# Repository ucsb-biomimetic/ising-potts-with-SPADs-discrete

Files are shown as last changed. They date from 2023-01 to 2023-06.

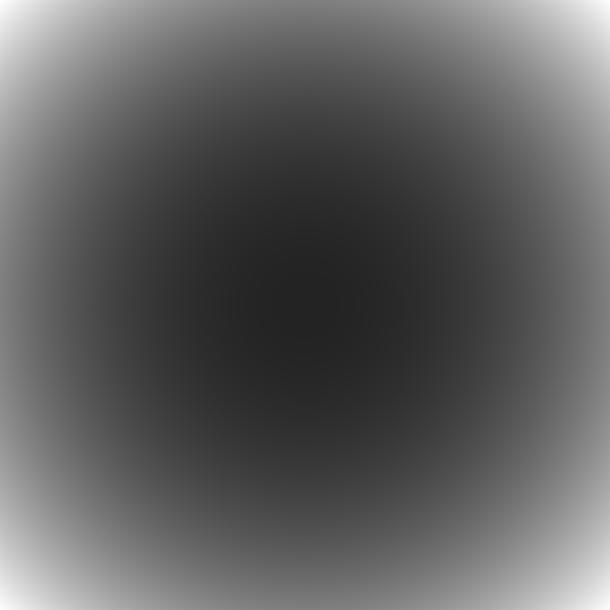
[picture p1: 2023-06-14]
VRSPAD-144/pcb_design/illumination box/illumination_mask.png

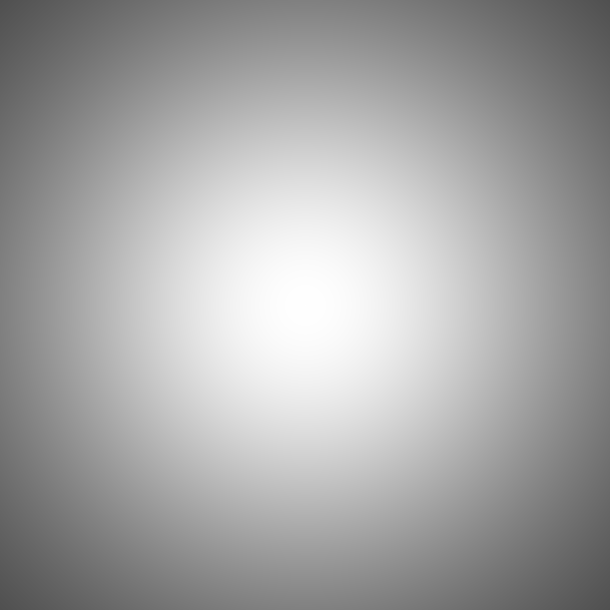
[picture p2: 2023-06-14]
VRSPAD-144/pcb_design/illumination box/intensity_map.png

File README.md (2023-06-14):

# ising-potts-with-SPADs-discrete
CMOS compatible Ising and Potts Annealing Using Single-photon Avalanche Diodes: Design files

The proof-of-concept for SPAD Ising and Potts CTMC (continuous-time markov chain) relies on the key files provided here.  There are two sets of files for 16-circuit and 144-circuit implementations of variable rate SPADs; the 144-circuit version was created second, to enable demonstrations of combinatorial problem solving.

For each implementation, there are three groups of files: one for PCB design, one for FPGA logic, and one for data and code. The code runs tests on the physical system specified by the PCB and FPGA design, and saves data results.

For the 16-circuit version, both the code and the FPGA configuration for the system lies entirely on the Zedboard; a Vivado 2020.1 project is provided, which was used to create the Zedboard FPGA configuration. The processor side of the Zedboard was configured to run linux and the PYNQ environment, so data collection and control of the proof-of-concept aparatus was done through a jupyter-notebook running locally on the zedboard (and accessed from a PC over ethernet).

Since the provided jupyter notebook runs in concert with the Zedboard FPGA and the hardware we connect to the FPGA, it cannot be run in its entirety without fully replicating the hardware as well.  However, many intermediate data are saved alongside the notebook, so one may see the interaction between code and results.  

For the 144-circuit version, the FPGA logic was redesigned to expose a SPI interface that could be accessed over a USB connection. Thus the Python code ran directly on a PC.  In addition, the FPGA board (A Digilent Genesys 2) was configured using Vivado 2020.1 in non-project mode, so rather than a Vivado project, regular verilog files and a Vivado TCL script provided.

While many of the scripts still require a connection to the hardware to run correctly, some scripts that only perform data plotting can be run without the hardware.

All experimental data in the paper is drawn from one of the two experimental systems specified here.

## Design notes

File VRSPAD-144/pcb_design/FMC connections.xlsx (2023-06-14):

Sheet: Sheet1
A | 0 | 1 | A1 | GND | #N/A | D8 | 141 | LA01_P_CC | H5 | 127 | CLK0_M2C_N
A | 1 | 2 | A2 | DP1_M2C_P | #N/A | D9 | 142 | LA01_N_CC | H4 | 128 | CLK0_M2C_P
A | 2 | 3 | A3 | DP1_M2C_N | #N/A | E10 | 144 | HA09_N | G3 | 131 | CLK1_M2C_N
A | 3 | 4 | A4 | GND | #N/A | E12 | 111 | HA13_P | G2 | 132 | CLK1_M2C_P
A | 4 | 5 | A5 | GND | #N/A | E13 | 105 | HA13_N | K5 | 122 | CLK2_BIDIR_N
A | 5 | 6 | A6 | DP2_M2C_P | #N/A | E15 | 99 | HA16_P | K4 | 124 | CLK2_BIDIR_P
A | 6 | 7 | A7 | DP2_M2C_N | #N/A | E16 | 93 | HA16_N | F5 | 135 | HA00_N_CC
A | 7 | 8 | A8 | GND | #N/A | E18 | 87 | HA20_P | F4 | 136 | HA00_P_CC
A | 8 | 9 | A9 | GND | #N/A | E19 | 81 | HA20_N | E3 | 138 | HA01_N_CC
A | 9 | 10 | A10 | DP3_M2C_P | #N/A | E2 | 137 | HA01_P_CC | E2 | 137 | HA01_P_CC
A | 10 | 11 | A11 | DP3_M2C_N | #N/A | E21 | 75 | HB03_P | K8 | 117 | HA02_N
A | 11 | 12 | A12 | GND | #N/A | E22 | 69 | HB03_N | K7 | 120 | HA02_P
A | 12 | 13 | A13 | GND | #N/A | E24 | 63 | HB05_P | J7 | 121 | HA03_N
A | 13 | 14 | A14 | DP4_M2C_P | #N/A | E25 | 57 | HB05_N | J6 | 123 | HA03_P
A | 14 | 15 | A15 | DP4_M2C_N | #N/A | E27 | 51 | HB09_P | F8 | 133 | HA04_N
A | 15 | 16 | A16 | GND | #N/A | E28 | 45 | HB09_N | F7 | 134 | HA04_P
A | 16 | 17 | A17 | GND | #N/A | E3 | 138 | HA01_N_CC | E7 | 140 | HA05_N
A | 17 | 18 | A18 | DP5_M2C_P | #N/A | E30 | 39 | HB13_P | E6 | 139 | HA05_P
A | 18 | 19 | A19 | DP5_M2C_N | #N/A | E31 | 33 | HB13_N | K11 | 106 | HA06_N
A | 19 | 20 | A20 | GND | #N/A | E33 | 24 | HB19_P | K10 | 112 | HA06_P
A | 20 | 21 | A21 | GND | #N/A | E34 | 21 | HB19_N | J10 | 113 | HA07_N
A | 21 | 22 | A22 | DP1_C2M_P | #N/A | E36 | 12 | HB21_P | J9 | 118 | HA07_P
A | 22 | 23 | A23 | DP1_C2M_N | #N/A | E37 | 1 | HB21_N | F11 | 110 | HA08_N
A | 23 | 24 | A24 | GND | #N/A | E6 | 139 | HA05_P | F10 | 116 | HA08_P
A | 24 | 25 | A25 | GND | #N/A | E7 | 140 | HA05_N | E10 | 144 | HA09_N
A | 25 | 26 | A26 | DP2_C2M_P | #N/A | E9 | 143 | HA09_P | E9 | 143 | HA09_P
A | 26 | 27 | A27 | DP2_C2M_N | #N/A | F10 | 116 | HA08_P | K14 | 94 | HA10_N
A | 27 | 28 | A28 | GND | #N/A | F11 | 110 | HA08_N | K13 | 100 | HA10_P
A | 28 | 29 | A29 | GND | #N/A | F13 | 104 | HA12_P | J13 | 101 | HA11_N
A | 29 | 30 | A30 | DP3_C2M_P | #N/A | F14 | 98 | HA12_N | J12 | 107 | HA11_P
A | 30 | 31 | A31 | DP3_C2M_N | #N/A | F16 | 92 | HA15_P | F14 | 98 | HA12_N
A | 31 | 32 | A32 | GND | #N/A | F17 | 86 | HA15_N | F13 | 104 | HA12_P
A | 32 | 33 | A33 | GND | #N/A | F19 | 80 | HA19_P | E13 | 105 | HA13_N
A | 33 | 34 | A34 | DP4_C2M_P | #N/A | F20 | 74 | HA19_N | E12 | 111 | HA13_P
A | 34 | 35 | A35 | DP4_C2M_N | #N/A | F22 | 68 | HB02_P | J16 | 89 | HA14_N
A | 35 | 36 | A36 | GND | #N/A | F23 | 62 | HB02_N | J15 | 95 | HA14_P
A | 36 | 37 | A37 | GND | #N/A | F25 | 56 | HB04_P | F17 | 86 | HA15_N
A | 37 | 38 | A38 | DP5_C2M_P | #N/A | F26 | 50 | HB04_N | F16 | 92 | HA15_P
A | 38 | 39 | A39 | DP5_C2M_N | #N/A | F28 | 44 | HB08_P | E16 | 93 | HA16_N
A | 39 | 40 | A40 | GND | #N/A | F29 | 38 | HB08_N | E15 | 99 | HA16_P
B | 40 | 1 | B1 | CLK_DIR | #N/A | F31 | 32 | HB12_P | K17 | 82 | HA17_N_CC
B | 41 | 2 | B2 | GND | #N/A | F32 | 27 | HB12_N | K16 | 88 | HA17_P_CC
B | 42 | 3 | B3 | GND | #N/A | F34 | 20 | HB16_P | J19 | 77 | HA18_N
B | 43 | 4 | B4 | DP9_M2C_P | #N/A | F35 | 15 | HB16_N | J18 | 83 | HA18_P
B | 44 | 5 | B5 | DP9_M2C_N | #N/A | F37 | 2 | HB20_P | F20 | 74 | HA19_N
B | 45 | 6 | B6 | GND | #N/A | F38 | 3 | HB20_N | F19 | 80 | HA19_P
B | 46 | 7 | B7 | GND | #N/A | F4 | 136 | HA00_P_CC | E19 | 81 | HA20_N
B | 47 | 8 | B8 | DP8_M2C_P | #N/A | F5 | 135 | HA00_N_CC | E18 | 87 | HA20_P
B | 48 | 9 | B9 | DP8_M2C_N | #N/A | F7 | 134 | HA04_P | K20 | 70 | HA21_N
B | 49 | 10 | B10 | GND | #N/A | F8 | 133 | HA04_N | K19 | 76 | HA21_P
B | 50 | 11 | B11 | GND | #N/A | G10 | 115 | LA03_N | J22 | 65 | HA22_N
B | 51 | 12 | B12 | DP7_M2C_P | #N/A | G12 | 109 | LA08_P | J21 | 71 | HA22_P
B | 52 | 13 | B13 | DP7_M2C_N | #N/A | G13 | 103 | LA08_N | K23 | 58 | HA23_N
B | 53 | 14 | B14 | GND | #N/A | G15 | 97 | LA12_P | K22 | 64 | HA23_P
B | 54 | 15 | B15 | GND | #N/A | G16 | 91 | LA12_N | K26 | 46 | HB00_N_CC
B | 55 | 16 | B16 | DP6_M2C_P | #N/A | G18 | 85 | LA16_P | K25 | 52 | HB00_P_CC
B | 56 | 17 | B17 | DP6_M2C_N | #N/A | G19 | 79 | LA16_N | J25 | 53 | HB01_N
B | 57 | 18 | B18 | GND | #N/A | G2 | 132 | CLK1_M2C_P | J24 | 59 | HB01_P
B | 58 | 19 | B19 | GND | #N/A | G21 | 73 | LA20_P | F23 | 62 | HB02_N
B | 59 | 20 | B20 | GBTCLK1_M2C_P | #N/A | G22 | 67 | LA20_N | F22 | 68 | HB02_P
B | 60 | 21 | B21 | GBTCLK1_M2C_N | #N/A | G24 | 61 | LA22_P | E22 | 69 | HB03_N
B | 61 | 22 | B22 | GND | #N/A | G25 | 55 | LA22_N | E21 | 75 | HB03_P
B | 62 | 23 | B23 | GND | #N/A | G27 | 49 | LA25_P | F26 | 50 | HB04_N
B | 63 | 24 | B24 | DP9_C2M_P | #N/A | G28 | 43 | LA25_N | F25 | 56 | HB04_P
B | 64 | 25 | B25 | DP9_C2M_N | #N/A | G3 | 131 | CLK1_M2C_N | E25 | 57 | HB05_N
B | 65 | 26 | B26 | GND | #N/A | G30 | 37 | LA29_P | E24 | 63 | HB05_P
B | 66 | 27 | B27 | GND | #N/A | G31 | 31 | LA29_N | K29 | 34 | HB06_N_CC
B | 67 | 28 | B28 | DP8_C2M_P | #N/A | G33 | 23 | LA31_P | K28 | 40 | HB06_P_CC
B | 68 | 29 | B29 | DP8_C2M_N | #N/A | G34 | 19 | LA31_N | J28 | 41 | HB07_N
B | 69 | 30 | B30 | GND | #N/A | G36 | 11 | LA33_P | J27 | 47 | HB07_P
B | 70 | 31 | B31 | GND | #N/A | G37 | 4 | LA33_N | F29 | 38 | HB08_N
B | 71 | 32 | B32 | DP7_C2M_P | #N/A | G6 | 130 | LA00_P_CC | F28 | 44 | HB08_P
B | 72 | 33 | B33 | DP7_C2M_N | #N/A | G7 | 129 | LA00_N_CC | E28 | 45 | HB09_N
B | 73 | 34 | B34 | GND | #N/A | G9 | 119 | LA03_P | E27 | 51 | HB09_P
B | 74 | 35 | B35 | GND | #N/A | H10 | 114 | LA04_P | K32 | 25 | HB10_N
B | 75 | 36 | B36 | DP6_C2M_P | #N/A | H11 | 108 | LA04_N | K31 | 28 | HB10_P
B | 76 | 37 | B37 | DP6_C2M_N | #N/A | H13 | 102 | LA07_P | J31 | 29 | HB11_N
B | 77 | 38 | B38 | GND | #N/A | H14 | 96 | LA07_N | J30 | 35 | HB11_P
B | 78 | 39 | B39 | GND | #N/A | H16 | 90 | LA11_P | F32 | 27 | HB12_N
B | 79 | 40 | B40 | RES0 | #N/A | H17 | 84 | LA11_N | F31 | 32 | HB12_P
C | 80 | 1 | C1 | GND | #N/A | H19 | 78 | LA15_P | E31 | 33 | HB13_N
C | 81 | 2 | C2 | DP0_C2M_P | #N/A | H20 | 72 | LA15_N | E30 | 39 | HB13_P
C | 82 | 3 | C3 | DP0_C2M_N | #N/A | H22 | 66 | LA19_P | K35 | 13 | HB14_N
C | 83 | 4 | C4 | GND | #N/A | H23 | 60 | LA19_N | K34 | 16 | HB14_P
C | 84 | 5 | C5 | GND | #N/A | H25 | 54 | LA21_P | J34 | 17 | HB15_N
C | 85 | 6 | C6 | DP0_M2C_P | #N/A | H26 | 48 | LA21_N | J33 | 22 | HB15_P
C | 86 | 7 | C7 | DP0_M2C_N | #N/A | H28 | 42 | LA24_P | F35 | 15 | HB16_N
C | 87 | 8 | C8 | GND | #N/A | H29 | 36 | LA24_N | F34 | 20 | HB16_P
C | 88 | 9 | C9 | GND | #N/A | H31 | 30 | LA28_P | K38 | 8 | HB17_N_CC
C | 89 | 10 | C10 | LA06_P | #N/A | H32 | 26 | LA28_N | K37 | 9 | HB17_P_CC
C | 90 | 11 | C11 | LA06_N | #N/A | H34 | 18 | LA30_P | J37 | 7 | HB18_N
C | 91 | 12 | C12 | GND | #N/A | H35 | 14 | LA30_N | J36 | 10 | HB18_P
C | 92 | 13 | C13 | GND | #N/A | H37 | 6 | LA32_P | E34 | 21 | HB19_N
C | 93 | 14 | C14 | LA10_P | #N/A | H38 | 5 | LA32_N | E33 | 24 | HB19_P
C | 94 | 15 | C15 | LA10_N | #N/A | H4 | 128 | CLK0_M2C_P | F38 | 3 | HB20_N
C | 95 | 16 | C16 | GND | #N/A | H5 | 127 | CLK0_M2C_N | F37 | 2 | HB20_P
C | 96 | 17 | C17 | GND | #N/A | H7 | 126 | LA02_P | E37 | 1 | HB21_N
C | 97 | 18 | C18 | LA14_P | #N/A | H8 | 125 | LA02_N | E36 | 12 | HB21_P
C | 98 | 19 | C19 | LA14_N | #N/A | J10 | 113 | HA07_N | G7 | 129 | LA00_N_CC
C | 99 | 20 | C20 | GND | #N/A | J12 | 107 | HA11_P | G6 | 130 | LA00_P_CC
C | 100 | 21 | C21 | GND | #N/A | J13 | 101 | HA11_N | D9 | 142 | LA01_N_CC
C | 101 | 22 | C22 | LA18_P_CC | #N/A | J15 | 95 | HA14_P | D8 | 141 | LA01_P_CC
C | 102 | 23 | C23 | LA18_N_CC | #N/A | J16 | 89 | HA14_N | H8 | 125 | LA02_N
C | 103 | 24 | C24 | GND | #N/A | J18 | 83 | HA18_P | H7 | 126 | LA02_P
C | 104 | 25 | C25 | GND | #N/A | J19 | 77 | HA18_N | G10 | 115 | LA03_N
C | 105 | 26 | C26 | LA27_P | #N/A | J21 | 71 | HA22_P | G9 | 119 | LA03_P
C | 106 | 27 | C27 | LA27_N | #N/A | J22 | 65 | HA22_N | H11 | 108 | LA04_N
C | 107 | 28 | C28 | GND | #N/A | J24 | 59 | HB01_P | H10 | 114 | LA04_P
C | 108 | 29 | C29 | GND | #N/A | J25 | 53 | HB01_N | H14 | 96 | LA07_N
C | 109 | 30 | C30 | SCL | #N/A | J27 | 47 | HB07_P | H13 | 102 | LA07_P
C | 110 | 31 | C31 | SDA | #N/A | J28 | 41 | HB07_N | G13 | 103 | LA08_N
C | 111 | 32 | C32 | GND | #N/A | J30 | 35 | HB11_P | G12 | 109 | LA08_P
C | 112 | 33 | C33 | GND | #N/A | J31 | 29 | HB11_N | H17 | 84 | LA11_N
C | 113 | 34 | C34 | GA0 | #N/A | J33 | 22 | HB15_P | H16 | 90 | LA11_P
C | 114 | 35 | C35 | 12P0V | #N/A | J34 | 17 | HB15_N | G16 | 91 | LA12_N
C | 115 | 36 | C36 | GND | #N/A | J36 | 10 | HB18_P | G15 | 97 | LA12_P
C | 116 | 37 | C37 | 12P0V | #N/A | J37 | 7 | HB18_N | H20 | 72 | LA15_N
C | 117 | 38 | C38 | GND | #N/A | J6 | 123 | HA03_P | H19 | 78 | LA15_P
C | 118 | 39 | C39 | 3P3V | #N/A | J7 | 121 | HA03_N | G19 | 79 | LA16_N
C | 119 | 40 | C40 | GND | #N/A | J9 | 118 | HA07_P | G18 | 85 | LA16_P
D | 120 | 1 | D1 | PG_C2M | #N/A | K10 | 112 | HA06_P | H23 | 60 | LA19_N
D | 121 | 2 | D2 | GND | #N/A | K11 | 106 | HA06_N | H22 | 66 | LA19_P
D | 122 | 3 | D3 | GND | #N/A | K13 | 100 | HA10_P | G22 | 67 | LA20_N
D | 123 | 4 | D4 | GBTCLK0_M2C_P | #N/A | K14 | 94 | HA10_N | G21 | 73 | LA20_P
D | 124 | 5 | D5 | GBTCLK0_M2C_N | #N/A | K16 | 88 | HA17_P_CC | H26 | 48 | LA21_N
D | 125 | 6 | D6 | GND | #N/A | K17 | 82 | HA17_N_CC | H25 | 54 | LA21_P
D | 126 | 7 | D7 | GND | #N/A | K19 | 76 | HA21_P | G25 | 55 | LA22_N
D | 127 | 8 | D8 | LA01_P_CC | 141 | K20 | 70 | HA21_N | G24 | 61 | LA22_P
D | 128 | 9 | D9 | LA01_N_CC | 142 | K22 | 64 | HA23_P | H29 | 36 | LA24_N
D | 129 | 10 | D10 | GND | #N/A | K23 | 58 | HA23_N | H28 | 42 | LA24_P
D | 130 | 11 | D11 | LA05_P | #N/A | K25 | 52 | HB00_P_CC | G28 | 43 | LA25_N
D | 131 | 12 | D12 | LA05_N | #N/A | K26 | 46 | HB00_N_CC | G27 | 49 | LA25_P
D | 132 | 13 | D13 | GND | #N/A | K28 | 40 | HB06_P_CC | H32 | 26 | LA28_N
D | 133 | 14 | D14 | LA09_P | #N/A | K29 | 34 | HB06_N_CC | H31 | 30 | LA28_P
D | 134 | 15 | D15 | LA09_N | #N/A | K31 | 28 | HB10_P | G31 | 31 | LA29_N
D | 135 | 16 | D16 | GND | #N/A | K32 | 25 | HB10_N | G30 | 37 | LA29_P
D | 136 | 17 | D17 | LA13_P | #N/A | K34 | 16 | HB14_P | H35 | 14 | LA30_N
D | 137 | 18 | D18 | LA13_N | #N/A | K35 | 13 | HB14_N | H34 | 18 | LA30_P
D | 138 | 19 | D19 | GND | #N/A | K37 | 9 | HB17_P_CC | G34 | 19 | LA31_N
D | 139 | 20 | D20 | LA17_P_CC | #N/A | K38 | 8 | HB17_N_CC | G33 | 23 | LA31_P
D | 140 | 21 | D21 | LA17_N_CC | #N/A | K4 | 124 | CLK2_BIDIR_P | H38 | 5 | LA32_N
D | 141 | 22 | D22 | GND | #N/A | K5 | 122 | CLK2_BIDIR_N | H37 | 6 | LA32_P
D | 142 | 23 | D23 | LA23_P | #N/A | K7 | 120 | HA02_P | G37 | 4 | LA33_N
D | 143 | 24 | D24 | LA23_N | #N/A | K8 | 117 | HA02_N | G36 | 11 | LA33_P
D | 144 | 25 | D25 | GND | #N/A | D14 | sck | LA09_P
D | 145 | 26 | D26 | LA26_P | #N/A | D12 | mosi | LA05_N
D | 146 | 27 | D27 | LA26_N | #N/A | D11 | miso | LA05_P
D | 147 | 28 | D28 | GND | #N/A | C10 | cs2 | LA06_P
D | 148 | 29 | D29 | TCK | #N/A | C11 | cs3 | LA06_N
D | 149 | 30 | D30 | TDI | #N/A | C14 | cs4 | LA10_P
D | 150 | 31 | D31 | TDO | #N/A | C15 | cs5 | LA10_N
D | 151 | 32 | D32 | 3P3VAUX | #N/A | C19 | A0 | LA14_N
D | 152 | 33 | D33 | TMS | #N/A | D20 | A1 | LA17_P_CC
D | 153 | 34 | D34 | TRST_L | #N/A | D27 | WR1 | LA26_N
D | 154 | 35 | D35 | GA1 | #N/A | C27 | WR2 | LA27_N
D | 155 | 36 | D36 | 3P3V | #N/A | D26 | WR3 | LA26_P
D | 156 | 37 | D37 | GND | #N/A | C26 | WR4 | LA27_P
D | 157 | 38 | D38 | 3P3V | #N/A | D24 | WR5 | LA23_N
D | 158 | 39 | D39 | GND | #N/A | C23 | WR6 | LA18_N_CC
D | 159 | 40 | D40 | 3P3V | #N/A | D23 | WR7 | LA23_P
E | 160 | 1 | E1 | GND | #N/A | C22 | WR8 | LA18_P_CC
E | 161 | 2 | E2 | HA01_P_CC | 137 | D21 | WR9 | LA17_N_CC
E | 162 | 3 | E3 | HA01_N_CC | 138 | C18 | HBEN | LA14_P
E | 163 | 4 | E4 | GND | #N/A
E | 164 | 5 | E5 | GND | #N/A
E | 165 | 6 | E6 | HA05_P | 139
E | 166 | 7 | E7 | HA05_N | 140
E | 167 | 8 | E8 | GND | #N/A
E | 168 | 9 | E9 | HA09_P | 143
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

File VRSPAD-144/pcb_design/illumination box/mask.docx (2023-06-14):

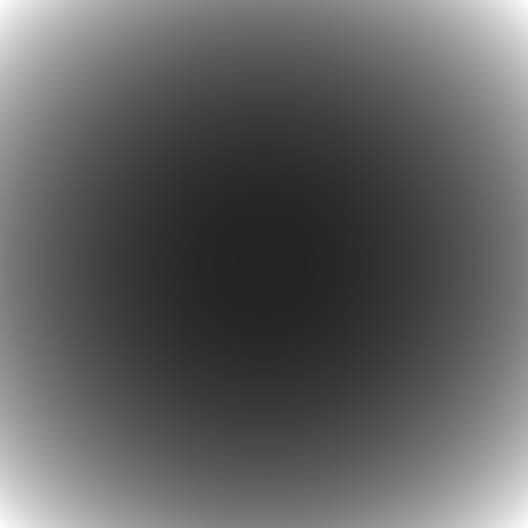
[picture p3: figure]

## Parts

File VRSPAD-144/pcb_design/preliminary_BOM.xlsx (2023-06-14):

item | PN | value | package | buy # | price each | line total | digikey link
modules
genesys 2 fpga |  |  |  | 1 |  | 0 | mouser
HX-8K eval board |  |  |  | 1 |  | 0 | mouser
144 element SiPM array | ARRAYC-30035-144P-PCB |  |  | 1 | 2255 | 2255 | mouser
adafruit FTDI breakout |  |  |  | 2 |  | 0 | mouser
connectors
bannana jack, black | CT3151SP-0 |  |  | 3 | 2.4 | 7.2 | mouser
bannana jack, red | CT3151SP-2 |  |  | 3 | 2.4 | 7.2 | mouser
bannana jack, green | CT3151SP-5 |  |  | 3 | 2.4 | 7.2 | mouser
FMC | ASP-134488-01 |  |  | 1 | 29.88 | 29.88 | mouser
SiPM array connector | QSE-040-01-F-D-A |  |  | 4 | 12.69 | 50.76 | mouser
PMOD cables |  |  |  | 7 |  |  | mouser
3A regulator | LD1085D2M-R |  | D2PAK/TO-263-3 | 3 | 2.08 | 6.24 | mouser
high voltage op amp | OPA990IDBVR |  | SOT-23-5 | 10 | 1.19 | 11.9 | https://www.digikey.com/en/products/detail/texas-instruments/OPA990IDBVR/11502246
medium power op amp | AD8531ARTZ |  | SOT-23-5 | 10 | 1.01 | 10.1 | https://www.digikey.com/en/products/detail/analog-devices-inc/AD8531ARTZ-REEL7/671108
global parameter DAC | AD5676ARUZ |  | TSSOP-20 | 2 | 21.46 | 42.92 | https://www.digikey.com/en/products/detail/analog-devices-inc/AD5676ARUZ-REEL7/5175797
signal circuits (array)
220 MHz 125 mA, 210 V/us | ADA4891-4ARUZ-R7 |  | TSSOP-14 | 2 | 4.04 | 8.08 | https://www.digikey.com/en/products/detail/analog-devices-inc/ADA4891-4ARUZ-R7/2606522
720 MHz quad op amp | LTC6254HMS |  | MSOP-14 | 2 | 12.87 | 25.74 | https://www.digikey.com/en/products/detail/analog-devices-inc/LTC6254HMS-PBF/2399171
quad DAC | AD7305BRUZ |  | TSSOP-20 | 2 | 13.4 | 26.8 | https://www.digikey.com/en/products/detail/analog-devices-inc/AD7305BRUZ-REEL7/760440
quad DAC | MAX5100AEUP+ |  |  |  |  |  | out of stock
quad comparator | MAX9201EUE+T |  | TSSOP-16 | 2 | 7 | 14 | https://www.digikey.com/en/products/detail/analog-devices-inc-maxim-integrated/MAX9201EUE-T/1499399
quad comparator | AD8564ARUZ |  | TSSOP-16 | 2 | 11.6 | 23.2 | https://www.digikey.com/en/products/detail/analog-devices-inc/AD8564ARUZ-REEL/751174
tia feedback resistor | resistor book - low R | 5.1k | _0402
end cap parts
octal level shifter | FXMA108BQX |  | DQFN-20 | 10 | 2.03 | 20.3 | https://www.digikey.com/en/products/detail/onsemi/FXMA108BQX/2287318?s=N4IgTCBcDaIGIA0CyBBAjABgBwgLoF8g
quad capacitor |  | 220n | _0508
quad resistor |  | _470 | _0508
0402 cap book
0.1u 0402 caps
3v3 version
quad comparator | MAX964EEE |  | QSOP-16 | 7 | 11 | 77 | https://www.digikey.com/en/products/detail/analog-devices-inc-maxim-integrated/MAX964EEE/948247
quad comparator | MAX964EEE |  | QSOP-16 | 35 | 8.63 | 302.05 | https://www.digikey.com/en/products/detail/analog-devices-inc-maxim-integrated/MAX964EEE/371671
quad amplifier | ADA4891-4ARUZ-R7 |  | TSSOP-14 | 43 | 4.04 | 173.72 | https://www.digikey.com/en/products/detail/analog-devices-inc/ADA4891-4ARUZ-R7/2606522
quad DAC | AD5335 |  | TSSOP-24 | 43 | 6.98 | 300.14 | https://www.digikey.com/en/products/detail/analog-devices-inc/AD5335BRU/11540879
720 MHz quad op amp | LTC6254HMS |  | MSOP-16 | 3 | 10.43 | 31.29

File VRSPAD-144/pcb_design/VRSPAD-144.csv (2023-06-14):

Source: | C:\Users\William\Documents\School files\research\ising potts SPAD CTMC node proof of concept\VRSPAD-144-pcb\VRSPAD-144.kicad_sch
Date: | 4/5/2023 1:55:15 PM
Tool: | Eeschema 7.0.1
Generator: | C:\Program Files\KiCad\6.0\bin\scripting\plugins/bom_csv_grouped_by_value_with_fp.py
Component Count: | 609
Ref | Qnty | Value | Cmp name | Footprint | Description | Vendor
adafruit_FT232H_alignment_guide1, | 1 | nopins | nopins | 0_kicad_custom_footprints:adafruit_FT232H_alignment_guide
ARRAYC-144P-alignment-guide1, | 1 | nopins | nopins | 0_kicad_custom_footprints:ARRAYC-144P-alignment_guide
BLK_1_1, BLK_1_2, BLK_1_3, BLK_1_4, BLK_1_5, BLK_1_6, BLK_1_7, BLK_1_8, BLK_1_9, BLK_1_10, BLK_1_11, BLK_1_12, BLK_1_13, BLK_1_14, BLK_1_15, BLK_1_16, BLK_1_17, BLK_1_18, BLK_1_19, BLK_1_20, BLK_1_21, BLK_1_22, BLK_1_23, BLK_1_24, BLK_1_25, BLK_1_26, BLK_1_27, BLK_1_28, BLK_1_29, BLK_1_30, BLK_1_31, BLK_1_32, BLK_1_33, BLK_1_34, BLK_1_35, BLK_1_36, | 36 | nopins | nopins | 0_kicad_custom_footprints:routing_guide_16T
C1, C190, C191, C192, C193, C194, C195, C197, C198, | 9 | 0.1u | C_Small | Capacitor_SMD:C_0603_1608Metric | Unpolarized capacitor, small symbol
C2, C3, C4, C5, C9, C10, C13, C14, C20, C21, C22, C23, C25, C26, C27, C28, C30, C31, C32, C33, C35, C36, C37, C38, C40, C41, C42, C43, C45, C46, C47, C48, C50, C51, C52, C53, C55, C56, C57, C58, C60, C61, C62, C63, C65, C66, C67, C68, C70, C71, C72, C73, C75, C76, C77, C78, C80, C81, C82, C83, C85, C86, C87, C88, C90, C91, C92, C93, C95, C96, C97, C98, C100, C101, C102, C103, C105, C106, C107, C108, C110, C111, C112, C113, C115, C116, C117, C118, C120, C121, C122, C123, C125, C126, C127, C128, C130, C131, C132, C133, C135, C136, C137, C138, C140, C141, C142, C143, C145, C146, C147, C148, C150, C151, C152, C153, C155, C156, C157, C158, C160, C161, C162, C163, C165, C166, C167, C168, C170, C171, C172, C173, C175, C176, C177, C178, C180, C181, C182, C183, C185, C186, C187, C188, | 144 | 0.1u | C_Small | Capacitor_SMD:C_0402_1005Metric | Unpolarized capacitor, small symbol
C6, C7, | 2 | 10u | C_Small | Capacitor_SMD:C_0603_1608Metric_Pad1.08x0.95mm_HandSolder | Unpolarized capacitor, small symbol
C8, C19, C24, C29, C34, C39, C44, C49, C54, C59, C64, C69, C74, C79, C84, C89, C94, C99, C104, C109, C114, C119, C124, C129, C134, C139, C144, C149, C154, C159, C164, C169, C174, C179, C184, C189, | 36 | C_Small | C_Small | Capacitor_SMD:C_0402_1005Metric | Unpolarized capacitor, small symbol
C11, C12, C15, C16, C17, C18, | 6 | 0.1u | C_Small | Capacitor_SMD:C_0603_1608Metric_Pad1.08x0.95mm_HandSolder | Unpolarized capacitor, small symbol
CN1, CN2, CN3, CN4, CN5, CN6, CN7, CN8, CN9, CN10, CN11, CN12, CN13, CN14, CN15, CN16, CN17, CN18, CN19, CN20, CN21, CN22, CN23, CN24, CN25, CN26, CN27, CN28, CN29, CN30, CN31, CN32, CN33, CN34, CN35, CN36, | 36 | 220p | C_Pack04 | Resistor_SMD:R_Array_Concave_4x0402 | 4 resistor network, parallel topology
D1, | 1 | LED | LED | LED_THT:LED_D5.0mm | Light emitting diode
FILT0, FILT1, FILT2, FILT3, FILT4, FILT5, FILT6, FILT7, FILT8, | 9 | nopins | nopins | 0_kicad_custom_footprints:array-end-routing-guide-16T
J1, J2, J3, J4, | 4 | Conn_02x06_Odd_Even | Conn_02x06_Odd_Even | Connector_PinHeader_2.54mm:PinHeader_2x06_P2.54mm_Horizontal | Generic connector, double row, 02x06, odd/even pin numbering scheme (row 1 odd numbers, row 2 even numbers), script generated (kicad-library-utils/schlib/autogen/connector/)
J5, J6, J13, | 3 | Conn_01x11 | Conn_01x11 | Connector_PinHeader_2.54mm:PinHeader_1x11_P2.54mm_Vertical | Generic connector, single row, 01x11, script generated (kicad-library-utils/schlib/autogen/connector/)
J7, | 1 | Conn_02x08_Odd_Even | Conn_02x08_Odd_Even | Connector_PinHeader_2.54mm:PinHeader_2x08_P2.54mm_Vertical | Generic connector, double row, 02x08, odd/even pin numbering scheme (row 1 odd numbers, row 2 even numbers), script generated (kicad-library-utils/schlib/autogen/connector/)
J8, J9, J10, J11, | 4 | QSE-040-01-X-D-A | QSE-040-01-X-D-A_ARRAYC-144 | 0_kicad_custom_footprints:SAMTEC_QSE-040-01-X-D-A
J12, | 1 | Samtec_ASP-134602-01 | Samtec_ASP-134602-01 | Connector_Samtec:Samtec_FMC_ASP-134602-01_10x40_P1.27mm_Vertical | Connector array, 10x40, 1.27mm pitch, mezzanine-card, plug, gold finish, VITA 57.1 FMC, SMD
J14, | 1 | Conn_01x06 | Conn_01x06 | Connector_PinHeader_2.54mm:PinHeader_1x06_P2.54mm_Vertical | Generic connector, single row, 01x06, script generated (kicad-library-utils/schlib/autogen/connector/)
J15, J16, J17, | 3 | Conn_Coaxial | Conn_Coaxial | Connector_Coaxial:SMA_Amphenol_132134-16_Vertical | coaxial connector (BNC, SMA, SMB, SMC, Cinch/RCA, LEMO, ...)
J18, | 1 | Conn_01x02 | Conn_01x02 | Connector_PinHeader_2.54mm:PinHeader_1x02_P2.54mm_Vertical | Generic connector, single row, 01x02, script generated (kicad-library-utils/schlib/autogen/connector/)
R1, R2, R8, R9, R10, R11, R12, R13, R14, R15, R16, R17, R18, R19, R20, R21, R22, R23, R24, R25, R26, R27, R28, R29, R30, R31, R32, R33, R34, R35, R36, R37, R38, R39, R40, R41, R42, R43, R44, R45, R46, R47, R48, R49, R50, R51, R52, R53, R54, R55, R56, R57, R58, R59, R60, R61, R62, R63, R64, R65, R66, R67, R68, R69, R70, R71, R72, R73, R74, R75, R76, R77, R78, R79, R80, R81, R82, R83, R84, R85, R86, R87, R88, R89, R90, R91, R92, R93, R94, R95, R96, R97, R98, R99, R100, R101, R102, R103, R104, R105, R106, R107, R108, R109, R110, R111, R112, R113, R114, R115, R116, R117, R118, R119, R120, R121, R122, R123, R124, R125, R126, R127, R128, R129, R130, R131, R132, R133, R134, R135, R136, R137, R138, R139, R140, R141, R142, R143, R144, R145, R146, R147, R148, R149, | 144 | 5.1k | R_Small_US | Resistor_SMD:R_0402_1005Metric | Resistor, small US symbol
R3, R5, | 2 | 1.1k | R_Small_US | Resistor_SMD:R_0603_1608Metric_Pad0.98x0.95mm_HandSolder | Resistor, small US symbol
R4, | 1 | 1.8k | R_Small_US | Resistor_SMD:R_0603_1608Metric_Pad0.98x0.95mm_HandSolder | Resistor, small US symbol
R6, | 1 | 1M | R_Small_US | Resistor_SMD:R_0603_1608Metric_Pad0.98x0.95mm_HandSolder | Resistor, small US symbol
R7, | 1 | 11k | R_Small_US | Resistor_SMD:R_0603_1608Metric_Pad0.98x0.95mm_HandSolder | Resistor, small US symbol
R150, | 1 | 470 | R_Small_US | Resistor_SMD:R_0603_1608Metric_Pad0.98x0.95mm_HandSolder | Resistor, small US symbol
RN1, RN2, RN3, RN4, RN5, RN6, RN7, RN8, RN9, RN10, RN11, RN12, RN13, RN14, RN15, RN16, RN17, RN18, RN19, RN20, RN21, RN22, RN23, RN24, RN25, RN26, RN27, RN28, RN29, RN30, RN31, RN32, RN33, RN34, RN35, RN36, | 36 | 470 | R_Pack04 | Resistor_SMD:R_Array_Concave_4x0402 | 4 resistor network, parallel topology
U1, | 1 | SensL_SiPM | SensL_SiPM | 0_kicad_custom_footprints:SensL_SiPM_3mm
U2, U14, U17, U20, U23, U26, U29, U32, U35, U38, U41, U44, U47, U50, U53, U56, U59, U62, U65, U68, U71, U74, U77, U80, U83, U86, U89, U92, U95, U98, U101, U104, U107, U110, U113, U116, | 36 | OPA4134 | OPA4134 | Package_SO:TSSOP-14_4.4x5mm_P0.65mm | Quad SoundPlus High Performance Audio Operational Amplifiers, SOIC-14
U3, U15, U18, U21, U24, U27, U30, U33, U36, U39, U42, U45, U48, U51, U54, U57, U60, U63, U66, U69, U72, U75, U78, U81, U84, U87, U90, U93, U96, U99, U102, U105, U108, U111, U114, U117, | 36 | MAX964 | MAX964 | Package_SO:QSOP-16_3.9x4.9mm_P0.635mm | Quad Rail-to-Rail Input/Output Amplifiers, TSSOP-14
U4, U5, U6, | 3 | bannana_jack | bannana_jack | 0_kicad_custom_footprints:CT3151-Horizontal
U7, | 1 | LD1086D2MTR | LD1086D2MTR | Package_TO_SOT_SMD:TO-263-3_TabPin2 | Positive, 1.5A 30V, Linear Regulator, Adjustable TO-263
U8, | 1 | AD5676 | AD5676 | Package_SO:TSSOP-20_4.4x6.5mm_P0.65mm
U9, U10, U12, U13, | 4 | AD8603 | AD8603 | Package_TO_SOT_SMD:TSOT-23-5 | Precision Micropower, Low Noise CMOS, Rail-to-Rail Input/Output Operational Amplifier, TSOT-23-5
U11, U16, U19, U22, U25, U28, U31, U34, U37, U40, U43, U46, U49, U52, U55, U58, U61, U64, U67, U70, U73, U76, U79, U82, U85, U88, U91, U94, U97, U100, U103, U106, U109, U112, U115, U118, | 36 | ~ | AD5335 | Package_SO:TSSOP-24_4.4x7.8mm_P0.65mm
U119, U120, U121, U122, U123, U124, | 6 | 74HCT541 | 74HCT541 | Package_SO:TSSOP-20_4.4x6.5mm_P0.65mm | 8-bit Buffer/Line Driver 3-state outputs

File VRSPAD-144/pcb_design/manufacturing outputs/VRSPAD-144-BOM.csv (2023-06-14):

description | Quantity | Part # | source | link | Reference designators
Quad op amp | 36 | ADA4891 | customer supplied |  | U2, U14, U17, U20, U23, U26, U29, U32, U35, U38, U41, U44, U47, U50, U53, U56, U59, U62, U65, U68, U71, U74, U77, U80, U83, U86, U89, U92, U95, U98, U101, U104, U107, U110, U113, U116,
Quad comparator | 36 | MAX964 | customer supplied |  | U3, U15, U18, U21, U24, U27, U30, U33, U36, U39, U42, U45, U48, U51, U54, U57, U60, U63, U66, U69, U72, U75, U78, U81, U84, U87, U90, U93, U96, U99, U102, U105, U108, U111, U114, U117,
Quad DAC | 36 | AD5335BRU | customer supplied |  | U11, U16, U19, U22, U25, U28, U31, U34, U37, U40, U43, U46, U49, U52, U55, U58, U61, U64, U67, U70, U73, U76, U79, U82, U85, U88, U91, U94, U97, U100, U103, U106, U109, U112, U115, U118,
capacitor, 0.1uF, 0402 | 180 | CL05A104KA5NNNC | Mouser | https://www.mouser.com/ProductDetail/Samsung-Electro-Mechanics/CL05A104KA5NNNC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 | C2, C3, C4, C5, C9, C10, C13, C14, C20, C21, C22, C23, C25, C26, C27, C28, C30, C31, C32, C33, C35, C36, C37, C38, C40, C41, C42, C43, C45, C46, C47, C48, C50, C51, C52, C53, C55, C56, C57, C58, C60, C61, C62, C63, C65, C66, C67, C68, C70, C71, C72, C73, C75, C76, C77, C78, C80, C81, C82, C83, C85, C86, C87, C88, C90, C91, C92, C93, C95, C96, C97, C98, C100, C101, C102, C103, C105, C106, C107, C108, C110, C111, C112, C113, C115, C116, C117, C118, C120, C121, C122, C123, C125, C126, C127, C128, C130, C131, C132, C133, C135, C136, C137, C138, C140, C141, C142, C143, C145, C146, C147, C148, C150, C151, C152, C153, C155, C156, C157, C158, C160, C161, C162, C163, C165, C166, C167, C168, C170, C171, C172, C173, C175, C176, C177, C178, C180, C181, C182, C183, C185, C186, C187, C188, C8, C19, C24, C29, C34, C39, C44, C49, C54, C59, C64, C69, C74, C79, C84, C89, C94, C99, C104, C109, C114, C119, C124, C129, C134, C139, C144, C149, C154, C159, C164, C169, C174, C179, C184, C189,
capacitor, 0.1uF, 0603 | 12 | CC0603JRX7R9BB104 | Mouser | https://www.mouser.com/ProductDetail/YAGEO/CC0603JRX7R9BB104?qs=57cj7OiSijmjSM%252BQadQODQ%3D%3D | C190, C191, C192, C193, C194, C195, C11, C12, C15, C16, C17, C18,
resistor, 5.1k, 0402 | 144 | RC0402FR-075K1L | Mouser | https://www.mouser.com/ProductDetail/YAGEO/RC0402FR-075K1L?qs=YUgVZYePFqCSmQuaha43RA%3D%3D | R1, R2, R8, R9, R10, R11, R12, R13, R14, R15, R16, R17, R18, R19, R20, R21, R22, R23, R24, R25, R26, R27, R28, R29, R30, R31, R32, R33, R34, R35, R36, R37, R38, R39, R40, R41, R42, R43, R44, R45, R46, R47, R48, R49, R50, R51, R52, R53, R54, R55, R56, R57, R58, R59, R60, R61, R62, R63, R64, R65, R66, R67, R68, R69, R70, R71, R72, R73, R74, R75, R76, R77, R78, R79, R80, R81, R82, R83, R84, R85, R86, R87, R88, R89, R90, R91, R92, R93, R94, R95, R96, R97, R98, R99, R100, R101, R102, R103, R104, R105, R106, R107, R108, R109, R110, R111, R112, R113, R114, R115, R116, R117, R118, R119, R120, R121, R122, R123, R124, R125, R126, R127, R128, R129, R130, R131, R132, R133, R134, R135, R136, R137, R138, R139, R140, R141, R142, R143, R144, R145, R146, R147, R148, R149,
resistor array, 470, 0805 | 36 | CAY10-471J4LF | Mouser | https://www.mouser.com/ProductDetail/Bourns/CAY10-471J4LF?qs=OfLg%252B8nW%252Blbp1HGC4k1dtQ%3D%3D | RN1, RN2, RN3, RN4, RN5, RN6, RN7, RN8, RN9, RN10, RN11, RN12, RN13, RN14, RN15, RN16, RN17, RN18, RN19, RN20, RN21, RN22, RN23, RN24, RN25, RN26, RN27, RN28, RN29, RN30, RN31, RN32, RN33, RN34, RN35, RN36,
capacitor array, 220p, 0805 | 36 | W2A45A221KAT2A | Mouser | https://www.mouser.com/ProductDetail/KYOCERA-AVX/W2A45A221KAT2A?qs=1X9trZCrWl29W6fmMy6ndg%3D%3D | CN1, CN2, CN3, CN4, CN5, CN6, CN7, CN8, CN9, CN10, CN11, CN12, CN13, CN14, CN15, CN16, CN17, CN18, CN19, CN20, CN21, CN22, CN23, CN24, CN25, CN26, CN27, CN28, CN29, CN30, CN31, CN32, CN33, CN34, CN35, CN36,
HPC FMC connector | 1 | ASP-134602-01 | Mouser | https://www.mouser.com/ProductDetail/Samtec/ASP-134602-01?qs=FESYatJ8odJXL2em%252Bh4I4Q%3D%3D | J12,
Q strip connector | 4 | QSE-040-01-F-D-A | Mouser | https://www.mouser.com/ProductDetail/Samtec/QSE-040-01-F-D-A?qs=92ilVni64gzKGoyyKQGXjw%3D%3D | J8, J9, J10, J11,
octal buffer | 6 | 74LVC541 | Mouser | https://www.mouser.com/ProductDetail/Nexperia/74LVC541APW118?qs=me8TqzrmIYXvoPByM7nnJQ%3D%3D | U119, U120, U121, U122, U123, U124,

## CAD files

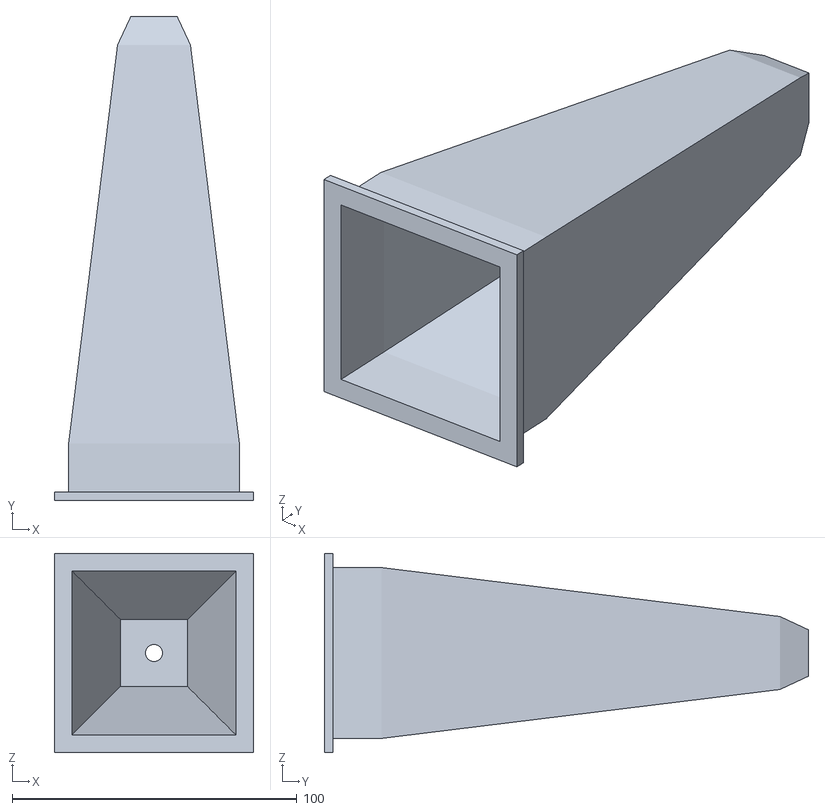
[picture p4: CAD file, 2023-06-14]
VRSPAD-144/pcb_design/illumination box/VRSPAD-144 illumination box.stl
70.0 x 170.0 x 70.0

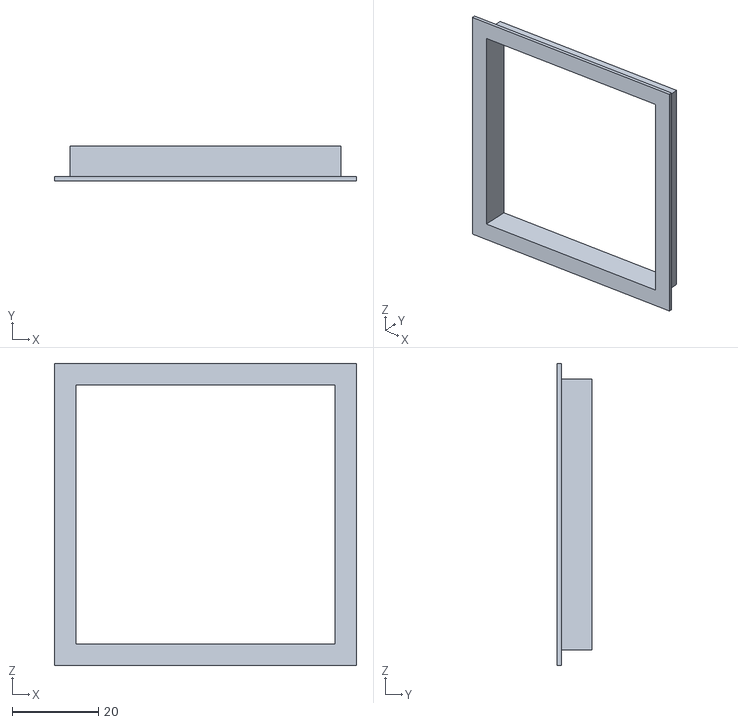
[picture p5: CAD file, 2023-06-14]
VRSPAD-144/pcb_design/illumination box/VRSPAD-144 illumination base.stl
70.0 x 8.00 x 70.0

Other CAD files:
VRSPAD-144/pcb_design/illumination box/OldVersions/VRSPAD-144 illumination box.0005.ipt
VRSPAD-144/pcb_design/illumination box/VRSPAD-144 illumination base.ipt
VRSPAD-144/pcb_design/illumination box/VRSPAD-144 illumination box.ipt

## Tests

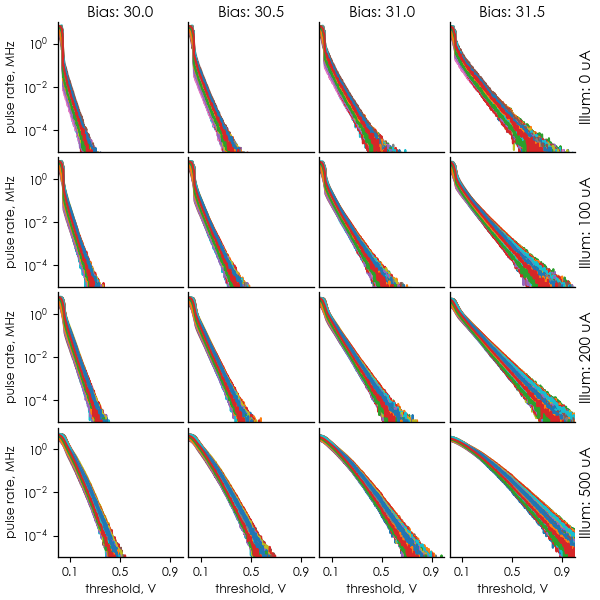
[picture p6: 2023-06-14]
VRSPAD-144/code_and_data/calibration/rate_curves.png

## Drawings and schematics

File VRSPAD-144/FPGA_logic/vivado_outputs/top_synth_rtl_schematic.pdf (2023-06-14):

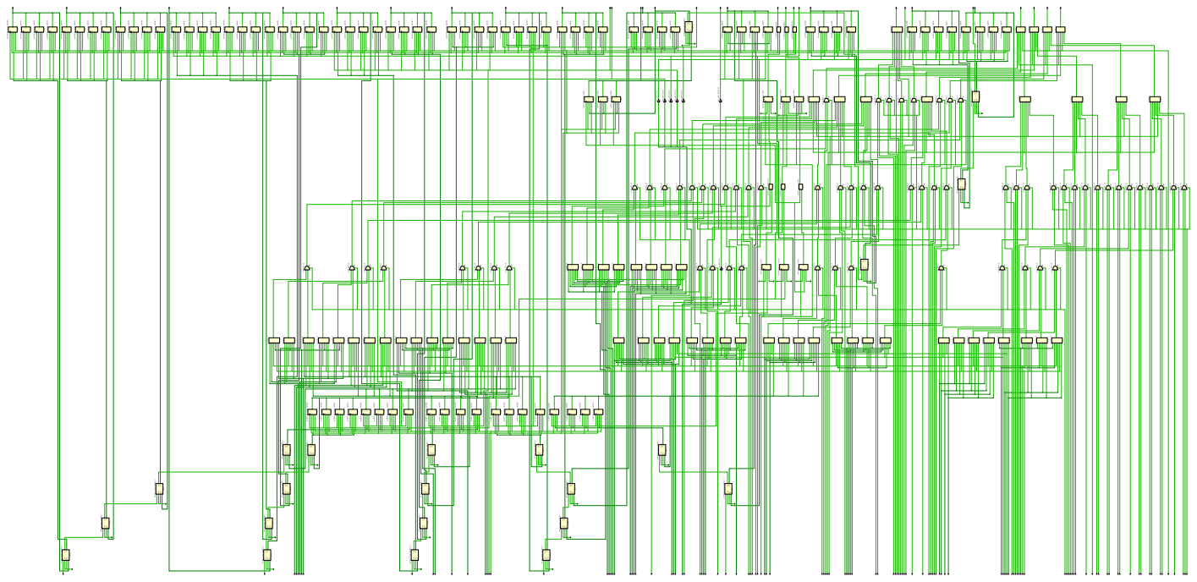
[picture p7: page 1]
genblk2[102].raw_counters_reg[102][28] FDRE Q C; CEDR; genblk2[102].raw_counters_reg[102][29] FDRE Q C; genblk2[102].raw_counters_reg[102][30] FDRE Q C; genblk2[102].raw_counters_reg[102][31] FDRE Q C; genblk2[100].raw_counters_reg[100][28] FDRE Q C; genblk2[100].raw_counters_reg[100][29] FDRE Q C; genblk2[100].raw_counters_reg[100][30] FDRE Q C; genblk2[100].raw_counters_reg[100][31] FDRE Q C; genblk2[116].raw_counters_reg[116][28] FDRE Q C; genblk2[116].raw_counters_reg[116][29] FDRE Q C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

genblk2[78].raw_counters_reg[78][0]_i_1 CARRY4 CI CYINIT CO[3:0] O[3:0] DI[3:0] V=B"0001" S[3:0]

I1 S genblk2[78].raw_counters_reg[78][12]_i_1 CARRY4 CI CYINIT CO[3:0] O[3:0] DI[3:0] S[3:0]

I1 S genblk2[78].raw_counters_reg[78][8]_i_1 CARRY4 CI CYINIT CO[3:0] O[3:0] DI[3:0] S[3:0]

I1 S genblk2[78].raw_counters_reg[78][4]_i_1 CARRY4 CI CYINIT CO[3:0] O[3:0] DI[3:0] S[3:0]

...k2[100].raw_counters_reg[100][28]_i_1 CARRY4 CI CYINIT CO[3:0] O[3:0] DI[3:0] S[3:0]

...k2[102].raw_counters_reg[102][28]_i_1 CARRY4 CI CYINIT CO[3:0] O[3:0] DI[3:0] S[3:0]

...k2[116].raw_counters_reg[116][28]_i_1 CARRY4 CI CYINIT CO[3:0] O[3:0] DI[3:0] S[3:0]

...k2[119].raw_counters_reg[119][28]_i_1 CARRY4 CI CYINIT CO[3:0] O[3:0] DI[3:0] S[3:0]

genblk2[72].raw_counters_reg[72][28]_i_1 CARRY4 CI CYINIT CO[3:0] O[3:0] DI[3:0] S[3:0]

genblk2[72].raw_counters_reg[72][24]_i_1 CARRY4 CI CYINIT CO[3:0] O[3:0] DI[3:0] S[3:0]

...k2[100].raw_counters_reg[100][24]_i_1 CARRY4 CI CYINIT CO[3:0] O[3:0] DI[3:0] S[3:0]

...k2[102].raw_counters_reg[102][24]_i_1 CARRY4 CI CYINIT CO[3:0] O[3:0] DI[3:0] S[3:0]

...k2[116].raw_counters_reg[116][24]_i_1 CARRY4 CI CYINIT CO[3:0] O[3:0] DI[3:0] S[3:0]

...k2[119].raw_counters_reg[119][24]_i_1 CARRY4 CI CYINIT CO[3:0] O[3:0] DI[3:0] S[3:0]

...k2[100].raw_counters_reg[100][20]_i_1 CARRY4 CI CYINIT CO[3:0] O[3:0] DI[3:0] S[3:0]

...k2[102].raw_counters_reg[102][20]_i_1 CARRY4 CI CYINIT CO[3:0] O[3:0] DI[3:0] S[3:0]

...k2[116].raw_counters_reg[116][20]_i_1 CARRY4 CI CYINIT CO[3:0] O[3:0] DI[3:0] S[3:0]

...k2[119].raw_counters_reg[119][20]_i_1 CARRY4 CI CYINIT CO[3:0] O[3:0] DI[3:0] S[3:0]

...k2[100].raw_counters_reg[100][16]_i_1 CARRY4 CI CYINIT CO[3:0] O[3:0] DI[3:0] S[3:0]

...k2[102].raw_counters_reg[102][16]_i_1 CARRY4 CI CYINIT CO[3:0] O[3:0] DI[3:0] S[3:0]

...k2[116].raw_counters_reg[116][16]_i_1 CARRY4 CI CYINIT CO[3:0] O[3:0] DI[3:0] S[3:0]

...k2[119].raw_counters_reg[119][16]_i_1 CARRY4 CI CYINIT CO[3:0] O[3:0] DI[3:0] S[3:0]

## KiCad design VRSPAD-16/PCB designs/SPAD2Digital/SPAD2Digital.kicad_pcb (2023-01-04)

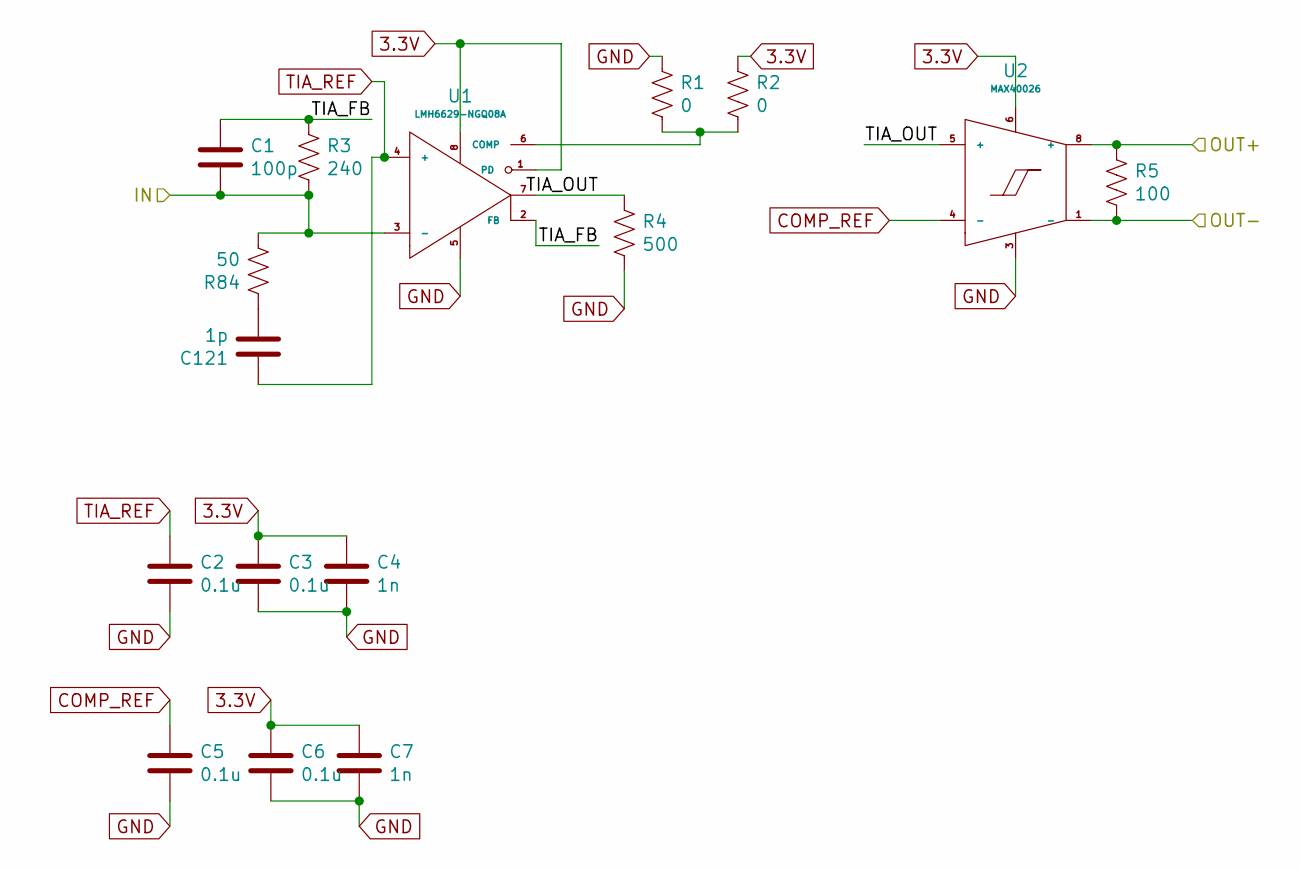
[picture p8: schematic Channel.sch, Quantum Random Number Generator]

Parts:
C114: 100p; C_0603_1608Metric
C115, C116, C118, C119: 0.1u; C_0603_1608Metric
C117, C120: 1n; C_0603_1608Metric
C136: 1p; C_0603_1608Metric
R79, R80: 0; R_0603_1608Metric
R81: 240; R_0603_1608Metric
R82: 500; R_0603_1608Metric
R83: 100; R_0603_1608Metric
R99: 50; R_0603_1608Metric
U8: MAX40026; TDFN-8-1EP_2x2mm_P0.5mm_EP0.8x1.2mm
U34: LMH6629-NGQ08A; WSON-8-1EP_3x3mm_P0.5mm_EP1.6x2.0mm

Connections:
3.3V: C116.1, C117.1, C119.1, C120.1, R80.1, U8.6, U8.7 (VCC), U34.1 (PD), U34.8; also elsewhere on the board
/A1: C114.2, R81.2, R99.2, U34.3 (-); also elsewhere on the board
/Channel_A1/TIA_FB: C114.1, R81.1, U34.2 (FB)
COMP_REF: C118.1, U8.4 (-); also elsewhere on the board
GND: C115.2, C116.2, C117.2, C118.2, C119.2, C120.2, R79.1, R82.2, U8.2 (GND), U8.3, U8.9 (EGP), U34.5, U34.9 (EGP); also elsewhere on the board
unnamed: C136.2, R99.1
unnamed: R79.2, R80.2, U34.6 (COMP)
TIA_REF: C115.1, C136.1, U34.4 (+); also elsewhere on the board

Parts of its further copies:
C1, C8, C15, C22, C29, C36, C43, C50, C57, C64, C71, C78, C85, C92, C99: 100p; C_0603_1608Metric
C2, C3, C5, C6, C9, C10, C12, C13, C16, C17, C19, C20, C23, C24, C26, C27, C30, C31, C33, C34, C37, C38, C40, C41, C44, C45, C47, C48, C51, C52, C54, C55, C58, C59, C61, C62, C65, C66, C68, C69, C72, C73, C75, C76, C79, C80, C82, C83, C86, C87, C89, C90, C93, C94, C96, C97, C100, C101, C103, C104: 0.1u; C_0603_1608Metric
C4, C7, C11, C14, C18, C21, C25, C28, C32, C35, C39, C42, C46, C49, C53, C56, C60, C63, C67, C70, C74, C77, C81, C84, C88, C91, C95, C98, C102, C105: 1n; C_0603_1608Metric
C121, C122, C123, C124, C125, C126, C127, C128, C129, C130, C131, C132, C133, C134, C135: 1p; C_0603_1608Metric
R1, R2, R6, R7, R11, R12, R16, R17, R21, R22, R26, R27, R31, R32, R36, R37, R41, R42, R46, R47, R51, R52, R56, R57, R61, R62, R66, R67, R71, R72: 0; R_0603_1608Metric
R3, R8, R13, R18, R23, R28, R33, R38, R43, R48, R53, R58, R63, R68, R73: 240; R_0603_1608Metric
R4, R9, R14, R19, R24, R29, R34, R39, R44, R49, R54, R59, R64, R69, R74: 500; R_0603_1608Metric
R5, R10, R15, R20, R25, R30, R35, R40, R45, R50, R55, R60, R65, R70, R75: 100; R_0603_1608Metric
R84, R85, R86, R87, R88, R89, R90, R91, R92, R93, R94, R95, R96, R97, R98: 50; R_0603_1608Metric
U1, U3, U5, U7, U9, U11, U13, U15, U17, U19, U21, U23, U25, U27, U29: LMH6629-NGQ08A; WSON-8-1EP_3x3mm_P0.5mm_EP1.6x2.0mm
U2, U4, U6, U10, U12, U14, U16, U18, U20, U22, U24, U26, U28, U30, U35: MAX40026; TDFN-8-1EP_2x2mm_P0.5mm_EP0.8x1.2mm

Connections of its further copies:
3.3V: C3.1, C4.1, C6.1, C7.1, C10.1, C11.1, C13.1, C14.1, C17.1, C18.1, C20.1, C21.1, C24.1, C25.1, C27.1, C28.1, C31.1, C32.1, C34.1, C35.1, C38.1, C39.1, C41.1, C42.1, C45.1, C46.1, C48.1, C49.1, C52.1, C53.1, C55.1, C56.1, C59.1, C60.1, C62.1, C63.1, C66.1, C67.1, C69.1, C70.1, C73.1, C74.1, C76.1, C77.1, C80.1, C81.1, C83.1, C84.1, C87.1, C88.1, C90.1, C91.1, C94.1, C95.1, C97.1, C98.1, C101.1, C102.1, C104.1, C105.1, R2.1, R7.1, R12.1, R17.1, R22.1, R27.1, R32.1, R37.1, R42.1, R47.1, R52.1, R57.1, R62.1, R67.1, R72.1, U1.1 (PD), U1.8, U2.6, U2.7 (VCC), U3.1 (PD), U3.8, U4.6, U4.7 (VCC), U5.1 (PD), U5.8, U6.6, U6.7 (VCC), U7.1 (PD), U7.8, U9.1 (PD), U9.8, U10.6, U10.7 (VCC), U11.1 (PD), U11.8, U12.6, U12.7 (VCC), U13.1 (PD), U13.8, U14.6, U14.7 (VCC), U15.1 (PD), U15.8, U16.6, U16.7 (VCC), U17.1 (PD), U17.8, U18.6, U18.7 (VCC), U19.1 (PD), U19.8, U20.6, U20.7 (VCC), U21.1 (PD), U21.8, U22.6, U22.7 (VCC), U23.1 (PD), U23.8, U24.6, U24.7 (VCC), U25.1 (PD), U25.8, U26.6, U26.7 (VCC), U27.1 (PD), U27.8, U28.6, U28.7 (VCC), U29.1 (PD), U29.8, U30.6, U30.7 (VCC), U35.6, U35.7 (VCC); also elsewhere on the board
/A2: C1.2, R3.2, R84.2, U1.3 (-); also elsewhere on the board
/A2_OUT_N: R5.2, U2.1 (-); also elsewhere on the board
/A2_OUT_P: R5.1, U2.8 (+); also elsewhere on the board
/A3: C8.2, R8.2, R85.2, U3.3 (-); also elsewhere on the board
/A3_OUT_N: R10.2, U4.1 (-); also elsewhere on the board
/A3_OUT_P: R10.1, U4.8 (+); also elsewhere on the board
/A4: C15.2, R13.2, R86.2, U5.3 (-); also elsewhere on the board
/A4_OUT_N: R15.2, U6.1 (-); also elsewhere on the board
/A4_OUT_P: R15.1, U6.8 (+); also elsewhere on the board
/B1: C22.2, R18.2, R87.2, U7.3 (-); also elsewhere on the board
/B2: C29.2, R23.2, R88.2, U9.3 (-); also elsewhere on the board
/B2_OUT_N: R25.2, U10.1 (-); also elsewhere on the board
/B2_OUT_P: R25.1, U10.8 (+); also elsewhere on the board
/B3: C36.2, R28.2, R89.2, U11.3 (-); also elsewhere on the board
/B3_OUT_N: R30.2, U12.1 (-); also elsewhere on the board
/B3_OUT_P: R30.1, U12.8 (+); also elsewhere on the board
/B4: C43.2, R33.2, R90.2, U13.3 (-); also elsewhere on the board
/B4_OUT_N: R35.2, U14.1 (-); also elsewhere on the board
/B4_OUT_P: R35.1, U14.8 (+); also elsewhere on the board
/C1: C50.2, R38.2, R91.2, U15.3 (-); also elsewhere on the board
/C1_OUT_N: R40.2, U16.1 (-); also elsewhere on the board
/C1_OUT_P: R40.1, U16.8 (+); also elsewhere on the board
/C2: C57.2, R43.2, R92.2, U17.3 (-); also elsewhere on the board
/C2_OUT_N: R45.2, U18.1 (-); also elsewhere on the board
/C2_OUT_P: R45.1, U18.8 (+); also elsewhere on the board
/C3: C64.2, R48.2, R93.2, U19.3 (-); also elsewhere on the board
/C3_OUT_N: R50.2, U20.1 (-); also elsewhere on the board
/C3_OUT_P: R50.1, U20.8 (+); also elsewhere on the board
/C4: C71.2, R53.2, R94.2, U21.3 (-); also elsewhere on the board
/C4_OUT_N: R55.2, U22.1 (-); also elsewhere on the board
/C4_OUT_P: R55.1, U22.8 (+); also elsewhere on the board
/Channel_A2/TIA_FB: C1.1, R3.1, U1.2 (FB)
/Channel_A2/TIA_OUT: R4.1, U1.7, U2.5 (+)
/Channel_A3/TIA_FB: C8.1, R8.1, U3.2 (FB)
/Channel_A3/TIA_OUT: R9.1, U3.7, U4.5 (+)
/Channel_A4/TIA_FB: C15.1, R13.1, U5.2 (FB)
/Channel_A4/TIA_OUT: R14.1, U5.7, U6.5 (+)
/Channel_B1/TIA_FB: C22.1, R18.1, U7.2 (FB)
/Channel_B2/TIA_FB: C29.1, R23.1, U9.2 (FB)
/Channel_B2/TIA_OUT: R24.1, U9.7, U10.5 (+)
/Channel_B3/TIA_FB: C36.1, R28.1, U11.2 (FB)
/Channel_B3/TIA_OUT: R29.1, U11.7, U12.5 (+)
/Channel_B4/TIA_FB: C43.1, R33.1, U13.2 (FB)
/Channel_B4/TIA_OUT: R34.1, U13.7, U14.5 (+)
/Channel_C1/TIA_FB: C50.1, R38.1, U15.2 (FB)
/Channel_C1/TIA_OUT: R39.1, U15.7, U16.5 (+)
/Channel_C2/TIA_FB: C57.1, R43.1, U17.2 (FB)
/Channel_C2/TIA_OUT: R44.1, U17.7, U18.5 (+)
/Channel_C3/TIA_FB: C64.1, R48.1, U19.2 (FB)
/Channel_C3/TIA_OUT: R49.1, U19.7, U20.5 (+)
/Channel_C4/TIA_FB: C71.1, R53.1, U21.2 (FB)
/Channel_C4/TIA_OUT: R54.1, U21.7, U22.5 (+)
/Channel_D1/TIA_FB: C78.1, R58.1, U23.2 (FB)
/Channel_D1/TIA_OUT: R59.1, U23.7, U24.5 (+); also elsewhere on the board
/Channel_D2/TIA_FB: C85.1, R63.1, U25.2 (FB)
/Channel_D2/TIA_OUT: R64.1, U25.7, U26.5 (+)
/Channel_D3/TIA_FB: C92.1, R68.1, U27.2 (FB)
/Channel_D3/TIA_OUT: R69.1, U27.7, U28.5 (+)
/Channel_D4/TIA_FB: C99.1, R73.1, U29.2 (FB)
/Channel_D4/TIA_OUT: R74.1, U29.7, U30.5 (+)
/D1: C78.2, R58.2, R95.2, U23.3 (-); also elsewhere on the board
/D1_OUT_N: R60.2, U24.1 (-); also elsewhere on the board
/D1_OUT_P: R60.1, U24.8 (+); also elsewhere on the board
/D2: C85.2, R63.2, R96.2, U25.3 (-); also elsewhere on the board
/D2_OUT_N: R65.2, U26.1 (-); also elsewhere on the board
/D2_OUT_P: R65.1, U26.8 (+); also elsewhere on the board
/D3: C92.2, R68.2, R97.2, U27.3 (-); also elsewhere on the board
/D3_OUT_N: R70.2, U28.1 (-); also elsewhere on the board
/D3_OUT_P: R70.1, U28.8 (+); also elsewhere on the board
/D4: C99.2, R73.2, R98.2, U29.3 (-); also elsewhere on the board
/D4_OUT_N: R75.2, U30.1 (-); also elsewhere on the board
/D4_OUT_P: R75.1, U30.8 (+); also elsewhere on the board
COMP_REF: C5.1, C12.1, C19.1, C26.1, C33.1, C40.1, C47.1, C54.1, C61.1, C68.1, C75.1, C82.1, C89.1, C96.1, C103.1, U2.4 (-), U4.4 (-), U6.4 (-), U10.4 (-), U12.4 (-), U14.4 (-), U16.4 (-), U18.4 (-), U20.4 (-), U22.4 (-), U24.4 (-), U26.4 (-), U28.4 (-), U30.4 (-), U35.4 (-); also elsewhere on the board
GND: C2.2, C3.2, C4.2, C5.2, C6.2, C7.2, C9.2, C10.2, C11.2, C12.2, C13.2, C14.2, C16.2, C17.2, C18.2, C19.2, C20.2, C21.2, C23.2, C24.2, C25.2, C26.2, C27.2, C28.2, C30.2, C31.2, C32.2, C33.2, C34.2, C35.2, C37.2, C38.2, C39.2, C40.2, C41.2, C42.2, C44.2, C45.2, C46.2, C47.2, C48.2, C49.2, C51.2, C52.2, C53.2, C54.2, C55.2, C56.2, C58.2, C59.2, C60.2, C61.2, C62.2, C63.2, C65.2, C66.2, C67.2, C68.2, C69.2, C70.2, C72.2, C73.2, C74.2, C75.2, C76.2, C77.2, C79.2, C80.2, C81.2, C82.2, C83.2, C84.2, C86.2, C87.2, C88.2, C89.2, C90.2, C91.2, C93.2, C94.2, C95.2, C96.2, C97.2, C98.2, C100.2, C101.2, C102.2, C103.2, C104.2, C105.2, R1.1, R4.2, R6.1, R9.2, R11.1, R14.2, R16.1, R19.2, R21.1, R24.2, R26.1, R29.2, R31.1, R34.2, R36.1, R39.2, R41.1, R44.2, R46.1, R49.2, R51.1, R54.2, R56.1, R59.2, R61.1, R64.2, R66.1, R69.2, R71.1, R74.2, U1.5, U1.9 (EGP), U2.2 (GND), U2.3, U2.9 (EGP), U3.5, U3.9 (EGP), U4.2 (GND), U4.3, U4.9 (EGP), U5.5, U5.9 (EGP), U6.2 (GND), U6.3, U6.9 (EGP), U7.5, U7.9 (EGP), U9.5, U9.9 (EGP), U10.2 (GND), U10.3, U10.9 (EGP), U11.5, U11.9 (EGP), U12.2 (GND), U12.3, U12.9 (EGP), U13.5, U13.9 (EGP), U14.2 (GND), U14.3, U14.9 (EGP), U15.5, U15.9 (EGP), U16.2 (GND), U16.3, U16.9 (EGP), U17.5, U17.9 (EGP), U18.2 (GND), U18.3, U18.9 (EGP), U19.5, U19.9 (EGP), U20.2 (GND), U20.3, U20.9 (EGP), U21.5, U21.9 (EGP), U22.2 (GND), U22.3, U22.9 (EGP), U23.5, U23.9 (EGP), U24.2 (GND), U24.3, U24.9 (EGP), U25.5, U25.9 (EGP), U26.2 (GND), U26.3, U26.9 (EGP), U27.5, U27.9 (EGP), U28.2 (GND), U28.3, U28.9 (EGP), U29.5, U29.9 (EGP), U30.2 (GND), U30.3, U30.9 (EGP), U35.2 (GND), U35.3, U35.9 (EGP); also elsewhere on the board
unnamed: C121.2, R84.1
unnamed: C122.2, R85.1
unnamed: C123.2, R86.1
unnamed: C124.2, R87.1
unnamed: C125.2, R88.1
unnamed: C126.2, R89.1
unnamed: C127.2, R90.1
unnamed: C128.2, R91.1
unnamed: C129.2, R92.1
unnamed: C130.2, R93.1
unnamed: C131.2, R94.1
unnamed: C132.2, R95.1
unnamed: C133.2, R96.1
unnamed: C134.2, R97.1
unnamed: C135.2, R98.1
unnamed: R1.2, R2.2, U1.6 (COMP)
unnamed: R6.2, R7.2, U3.6 (COMP)
unnamed: R11.2, R12.2, U5.6 (COMP)
unnamed: R16.2, R17.2, U7.6 (COMP)
unnamed: R21.2, R22.2, U9.6 (COMP)
unnamed: R26.2, R27.2, U11.6 (COMP)
unnamed: R31.2, R32.2, U13.6 (COMP)
unnamed: R36.2, R37.2, U15.6 (COMP)
unnamed: R41.2, R42.2, U17.6 (COMP)
unnamed: R46.2, R47.2, U19.6 (COMP)
unnamed: R51.2, R52.2, U21.6 (COMP)
unnamed: R56.2, R57.2, U23.6 (COMP)
unnamed: R61.2, R62.2, U25.6 (COMP)
unnamed: R66.2, R67.2, U27.6 (COMP)
unnamed: R71.2, R72.2, U29.6 (COMP)
TIA_REF: C2.1, C9.1, C16.1, C23.1, C30.1, C37.1, C44.1, C51.1, C58.1, C65.1, C72.1, C79.1, C86.1, C93.1, C100.1, C121.1, C122.1, C123.1, C124.1, C125.1, C126.1, C127.1, C128.1, C129.1, C130.1, C131.1, C132.1, C133.1, C134.1, C135.1, U1.4 (+), U3.4 (+), U5.4 (+), U7.4 (+), U9.4 (+), U11.4 (+), U13.4 (+), U15.4 (+), U17.4 (+), U19.4 (+), U21.4 (+), U23.4 (+), U25.4 (+), U27.4 (+), U29.4 (+); also elsewhere on the board

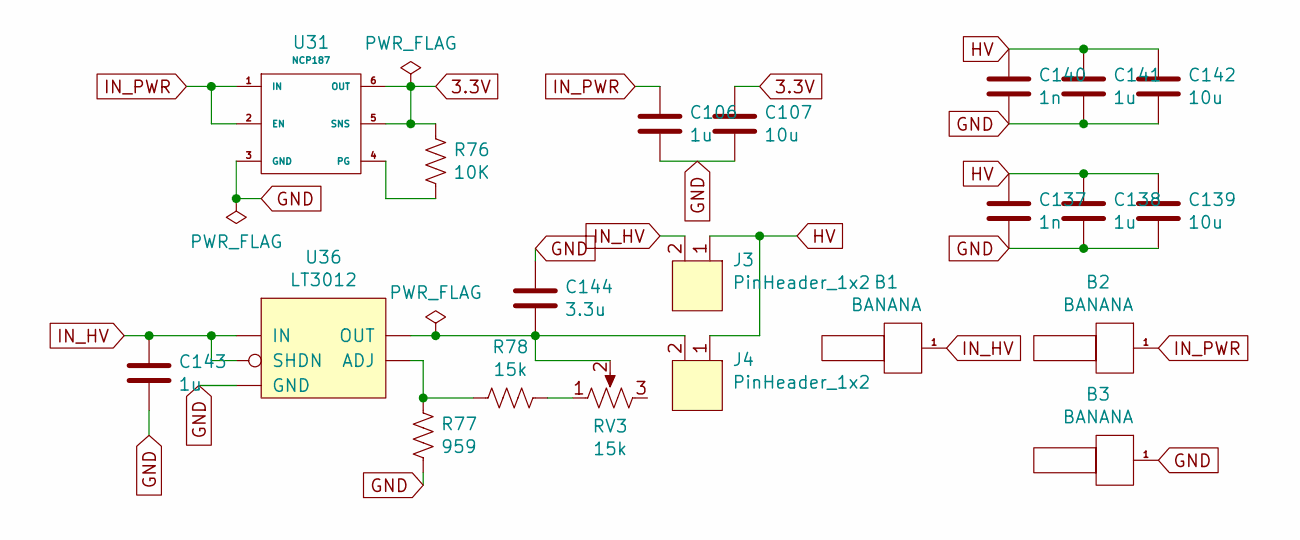
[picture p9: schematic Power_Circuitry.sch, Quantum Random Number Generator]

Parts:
B1, B2, B3: BANANA; CT3151-Horizontal
C106, C138, C141, C143: 1u; C_0603_1608Metric
C107, C139, C142: 10u; C_0603_1608Metric
C137, C140: 1n; C_0603_1608Metric
C144: 3.3u; C_0603_1608Metric
J3, J4: PinHeader_1x2; PinHeader_1x02_P2.54mm_Vertical
R76: 10K; R_0603_1608Metric
R77: 959; R_0603_1608Metric
R78: 15k; R_0603_1608Metric
RV3: 15k; Potentiometer_Bourns_3296W_Vertical
U31: NCP187; WDFN-6-1EP_2x2mm_P0.65mm_EP1.12x1.72
U36: LT3012; TSSOP-16-1EP_4.4x5mm_P0.65mm

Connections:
3.3V: C107.1, R76.1, U31.5 (SNS), U31.6 (OUT); also elsewhere on the board
GND: B3.1, C106.2, C107.2, C137.2, C138.2, C139.2, C140.2, C141.2, C142.2, C143.2, C144.1, R77.2, U31.3 (GND), U31.7, U36.1 (GND), U36.6, U36.8, U36.9, U36.16, U36.17; also elsewhere on the board
HV: C137.1, C138.1, C139.1, C140.1, C141.1, C142.1, J3.1, J4.1; also elsewhere on the board
IN_HV: B1.1, C143.1, J3.2, U36.11 (SHDN), U36.13 (IN), U36.14
IN_PWR: B2.1, C106.1, U31.1 (IN), U31.2 (EN)
unnamed: C144.2, J4.2, RV3.2, U36.3 (OUT), U36.4
unnamed: R76.2, U31.4 (PG)
unnamed: R77.1, R78.2, U36.5 (ADJ)
unnamed: R78.1, RV3.1

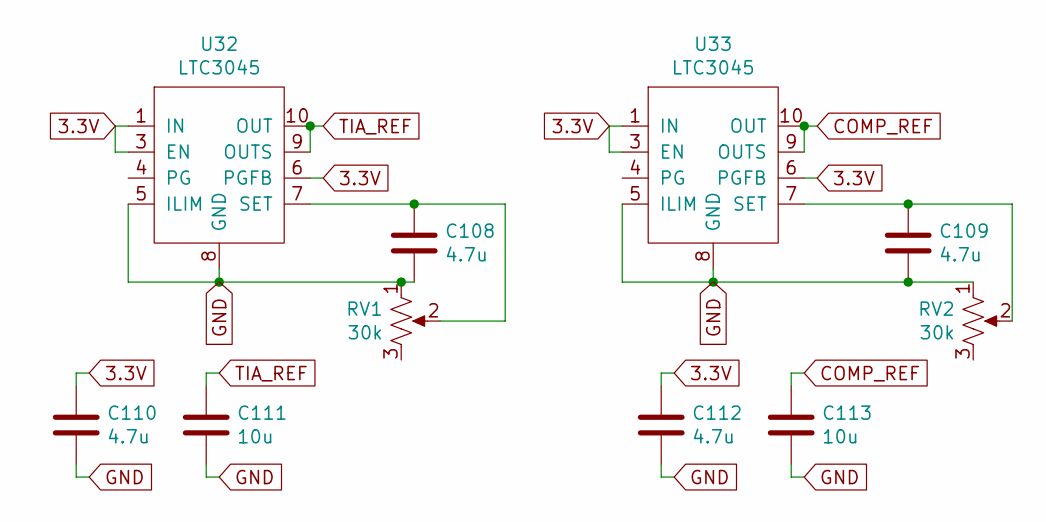
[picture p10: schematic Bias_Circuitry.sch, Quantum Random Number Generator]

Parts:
C108, C109, C110, C112: 4.7u; C_0603_1608Metric
C111, C113: 10u; C_0603_1608Metric
RV1, RV2: 30k; Potentiometer_Bourns_3296W_Vertical
U32, U33: LTC3045; DFN-10-1EP_3x3mm_P0.5mm_EP1.65x2.38mm

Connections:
3.3V: C110.1, C112.1, U32.1 (IN), U32.2, U32.3 (EN), U32.6 (PGFB), U33.1 (IN), U33.2, U33.3 (EN), U33.6 (PGFB); also elsewhere on the board
COMP_REF: C113.1, U33.9 (OUTS), U33.10 (OUT); also elsewhere on the board
GND: C108.2, C109.2, C110.2, C111.2, C112.2, C113.2, RV1.1, RV2.1, U32.5 (ILIM), U32.8 (GND), U32.11, U33.5 (ILIM), U33.8 (GND), U33.11; also elsewhere on the board
unnamed 112: C108.1, RV1.2, U32.7 (SET); also elsewhere on the board
unnamed 113: C109.1, RV2.2, U33.7 (SET); also elsewhere on the board
TIA_REF: C111.1, U32.9 (OUTS), U32.10 (OUT); also elsewhere on the board

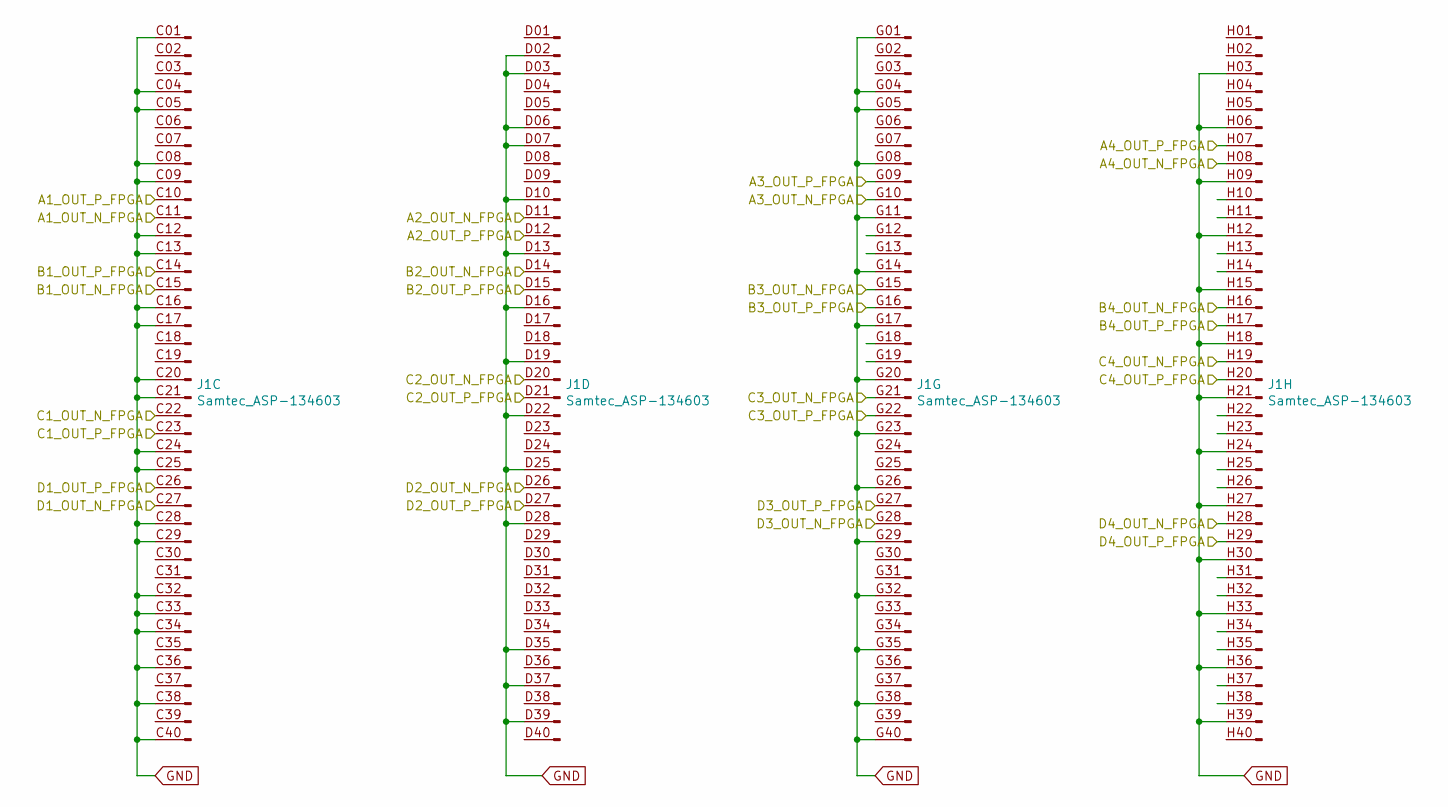
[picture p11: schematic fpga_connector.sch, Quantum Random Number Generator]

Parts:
J1: Samtec_ASP-134603; Samtec_FMC_ASP-134604-01_4x40_Vertical

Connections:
/A2_OUT_N: J1.D11 (Pin_11); also elsewhere on the board
/A2_OUT_P: J1.D12 (Pin_12); also elsewhere on the board
/A3_OUT_N: J1.G10 (Pin_10); also elsewhere on the board
/A3_OUT_P: J1.G09 (Pin_9); also elsewhere on the board
/A4_OUT_N: J1.H08 (Pin_8); also elsewhere on the board
/A4_OUT_P: J1.H07 (Pin_7); also elsewhere on the board
/B2_OUT_N: J1.D14 (Pin_14); also elsewhere on the board
/B2_OUT_P: J1.D15 (Pin_15); also elsewhere on the board
/B3_OUT_N: J1.G15 (Pin_15); also elsewhere on the board
/B3_OUT_P: J1.G16 (Pin_16); also elsewhere on the board
/B4_OUT_N: J1.H16 (Pin_16); also elsewhere on the board
/B4_OUT_P: J1.H17 (Pin_17); also elsewhere on the board
/C1_OUT_N: J1.C22 (Pin_22); also elsewhere on the board
/C1_OUT_P: J1.C23 (Pin_23); also elsewhere on the board
/C2_OUT_N: J1.D20 (Pin_20); also elsewhere on the board
/C2_OUT_P: J1.D21 (Pin_21); also elsewhere on the board
/C3_OUT_N: J1.G21 (Pin_21); also elsewhere on the board
/C3_OUT_P: J1.G22 (Pin_22); also elsewhere on the board
/C4_OUT_N: J1.H19 (Pin_19); also elsewhere on the board
/C4_OUT_P: J1.H20 (Pin_20); also elsewhere on the board
/D1_OUT_N: J1.C27 (Pin_27); also elsewhere on the board
/D1_OUT_P: J1.C26 (Pin_26); also elsewhere on the board
/D2_OUT_N: J1.D26 (Pin_26); also elsewhere on the board
/D2_OUT_P: J1.D27 (Pin_27); also elsewhere on the board
/D3_OUT_N: J1.G28 (Pin_28); also elsewhere on the board
/D3_OUT_P: J1.G27 (Pin_27); also elsewhere on the board
/D4_OUT_N: J1.H28 (Pin_28); also elsewhere on the board
/D4_OUT_P: J1.H29 (Pin_29); also elsewhere on the board
GND: J1.C01 (Pin_1), J1.C04 (Pin_4), J1.C05 (Pin_5), J1.C08 (Pin_8), J1.C09 (Pin_9), J1.C12 (Pin_12), J1.C13 (Pin_13), J1.C16 (Pin_16), J1.C17 (Pin_17), J1.C20 (Pin_20), J1.C21 (Pin_21), J1.C24 (Pin_24), J1.C25 (Pin_25), J1.C28 (Pin_28), J1.C29 (Pin_29), J1.C32 (Pin_32), J1.C33 (Pin_33), J1.C34 (Pin_34), J1.C36 (Pin_36), J1.C38 (Pin_38), J1.C40 (Pin_40), J1.D02 (Pin_2), J1.D03 (Pin_3), J1.D06 (Pin_6), J1.D07 (Pin_7), J1.D10 (Pin_10), J1.D13 (Pin_13), J1.D16 (Pin_16), J1.D19 (Pin_19), J1.D22 (Pin_22), J1.D25 (Pin_25), J1.D28 (Pin_28), J1.D35 (Pin_35), J1.D37 (Pin_37), J1.D39 (Pin_39), J1.G01 (Pin_1), J1.G04 (Pin_4), J1.G05 (Pin_5), J1.G08 (Pin_8), J1.G11 (Pin_11), J1.G14 (Pin_14), J1.G17 (Pin_17), J1.G20 (Pin_20), J1.G23 (Pin_23), J1.G26 (Pin_26), J1.G29 (Pin_29), J1.G32 (Pin_32), J1.G35 (Pin_35), J1.G38 (Pin_38), J1.G40 (Pin_40), J1.H03 (Pin_3), J1.H06 (Pin_6), J1.H09 (Pin_9), J1.H12 (Pin_12), J1.H15 (Pin_15), J1.H18 (Pin_18), J1.H21 (Pin_21), J1.H24 (Pin_24), J1.H27 (Pin_27), J1.H30 (Pin_30), J1.H33 (Pin_33), J1.H36 (Pin_36), J1.H39 (Pin_39); also elsewhere on the board

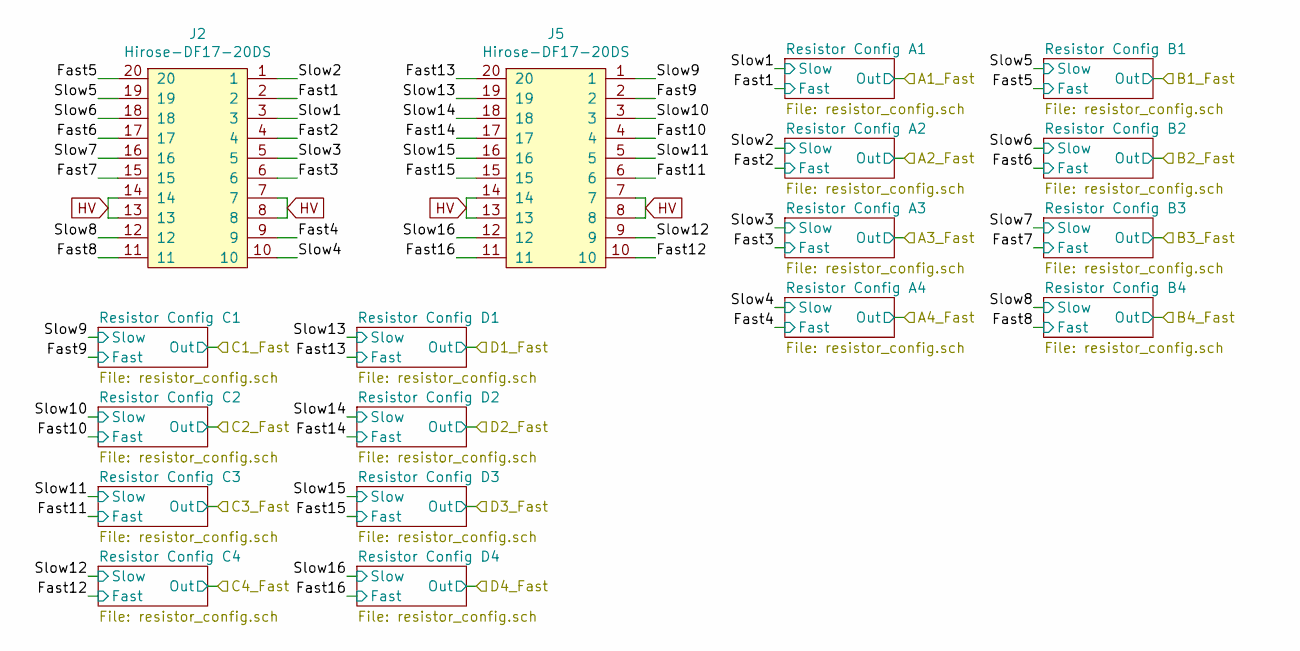
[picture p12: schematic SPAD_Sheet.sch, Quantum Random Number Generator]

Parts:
J2, J5: Hirose-DF17-20DS; Hirose_DF17-20DS_2x10_P0.50mm_Vertical_Mate

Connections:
/SPAD Sheet/Fast1: J2.2; also elsewhere on the board
/SPAD Sheet/Fast2: J2.4; also elsewhere on the board
/SPAD Sheet/Fast3: J2.6; also elsewhere on the board
/SPAD Sheet/Fast4: J2.9; also elsewhere on the board
/SPAD Sheet/Fast5: J2.20; also elsewhere on the board
/SPAD Sheet/Fast6: J2.17; also elsewhere on the board
/SPAD Sheet/Fast7: J2.15; also elsewhere on the board
/SPAD Sheet/Fast8: J2.11; also elsewhere on the board
/SPAD Sheet/Fast9: J5.2; also elsewhere on the board
/SPAD Sheet/Fast10: J5.4; also elsewhere on the board
/SPAD Sheet/Fast11: J5.6; also elsewhere on the board
/SPAD Sheet/Fast12: J5.10; also elsewhere on the board
/SPAD Sheet/Fast13: J5.20; also elsewhere on the board
/SPAD Sheet/Fast14: J5.17; also elsewhere on the board
/SPAD Sheet/Fast15: J5.15; also elsewhere on the board
/SPAD Sheet/Fast16: J5.11; also elsewhere on the board
/SPAD Sheet/Slow1: J2.3; also elsewhere on the board
/SPAD Sheet/Slow2: J2.1; also elsewhere on the board
/SPAD Sheet/Slow3: J2.5; also elsewhere on the board
/SPAD Sheet/Slow4: J2.10; also elsewhere on the board
/SPAD Sheet/Slow5: J2.19; also elsewhere on the board
/SPAD Sheet/Slow6: J2.18; also elsewhere on the board
/SPAD Sheet/Slow7: J2.16; also elsewhere on the board
/SPAD Sheet/Slow8: J2.12; also elsewhere on the board
/SPAD Sheet/Slow9: J5.1; also elsewhere on the board
/SPAD Sheet/Slow10: J5.3; also elsewhere on the board
/SPAD Sheet/Slow11: J5.5; also elsewhere on the board
/SPAD Sheet/Slow12: J5.9; also elsewhere on the board
/SPAD Sheet/Slow13: J5.19; also elsewhere on the board
/SPAD Sheet/Slow14: J5.18; also elsewhere on the board
/SPAD Sheet/Slow15: J5.16; also elsewhere on the board
/SPAD Sheet/Slow16: J5.12; also elsewhere on the board
HV: J2.7, J2.8, J2.13, J2.14, J5.7, J5.8, J5.13, J5.14; also elsewhere on the board

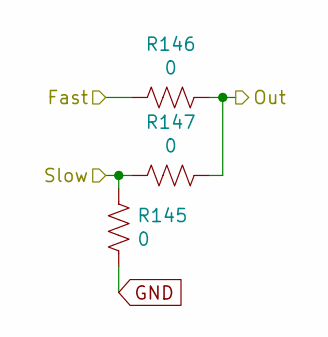
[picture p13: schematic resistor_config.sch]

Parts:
R100, R101, R102: 0; R_0603_1608Metric

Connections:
/A1: R101.2, R102.2; also elsewhere on the board
/SPAD Sheet/Fast1: R101.1; also elsewhere on the board
/SPAD Sheet/Slow1: R100.1, R102.1; also elsewhere on the board
GND: R100.2; also elsewhere on the board

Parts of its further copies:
R103, R104, R105, R106, R107, R108, R109, R110, R111, R112, R113, R114, R115, R116, R117, R118, R119, R120, R121, R122, R123, R124, R125, R126, R127, R128, R129, R130, R131, R132, R133, R134, R135, R136, R137, R138, R139, R140, R141, R142, R143, R144, R145, R146, R147: 0; R_0603_1608Metric

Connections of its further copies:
/A2: R104.2, R105.2; also elsewhere on the board
/A3: R107.2, R108.2; also elsewhere on the board
/A4: R110.2, R111.2; also elsewhere on the board
/B1: R113.2, R114.2; also elsewhere on the board
/B2: R116.2, R117.2; also elsewhere on the board
/B3: R119.2, R120.2; also elsewhere on the board
/B4: R122.2, R123.2; also elsewhere on the board
/C1: R125.2, R126.2; also elsewhere on the board
/C2: R128.2, R129.2; also elsewhere on the board
/C3: R131.2, R132.2; also elsewhere on the board
/C4: R134.2, R135.2; also elsewhere on the board
/D1: R137.2, R138.2; also elsewhere on the board
/D2: R140.2, R141.2; also elsewhere on the board
/D3: R143.2, R144.2; also elsewhere on the board
/D4: R146.2, R147.2; also elsewhere on the board
/SPAD Sheet/Fast2: R104.1; also elsewhere on the board
/SPAD Sheet/Fast3: R107.1; also elsewhere on the board
/SPAD Sheet/Fast4: R110.1; also elsewhere on the board
/SPAD Sheet/Fast5: R113.1; also elsewhere on the board
/SPAD Sheet/Fast6: R116.1; also elsewhere on the board
/SPAD Sheet/Fast7: R119.1; also elsewhere on the board
/SPAD Sheet/Fast8: R122.1; also elsewhere on the board
/SPAD Sheet/Fast9: R125.1; also elsewhere on the board
/SPAD Sheet/Fast10: R128.1; also elsewhere on the board
/SPAD Sheet/Fast11: R131.1; also elsewhere on the board
/SPAD Sheet/Fast12: R134.1; also elsewhere on the board
/SPAD Sheet/Fast13: R137.1; also elsewhere on the board
/SPAD Sheet/Fast14: R140.1; also elsewhere on the board
/SPAD Sheet/Fast15: R143.1; also elsewhere on the board
/SPAD Sheet/Fast16: R146.1; also elsewhere on the board
/SPAD Sheet/Slow2: R103.1, R105.1; also elsewhere on the board
/SPAD Sheet/Slow3: R106.1, R108.1; also elsewhere on the board
/SPAD Sheet/Slow4: R109.1, R111.1; also elsewhere on the board
/SPAD Sheet/Slow5: R112.1, R114.1; also elsewhere on the board
/SPAD Sheet/Slow6: R115.1, R117.1; also elsewhere on the board
/SPAD Sheet/Slow7: R118.1, R120.1; also elsewhere on the board
/SPAD Sheet/Slow8: R121.1, R123.1; also elsewhere on the board
/SPAD Sheet/Slow9: R124.1, R126.1; also elsewhere on the board
/SPAD Sheet/Slow10: R127.1, R129.1; also elsewhere on the board
/SPAD Sheet/Slow11: R130.1, R132.1; also elsewhere on the board
/SPAD Sheet/Slow12: R133.1, R135.1; also elsewhere on the board
/SPAD Sheet/Slow13: R136.1, R138.1; also elsewhere on the board
/SPAD Sheet/Slow14: R139.1, R141.1; also elsewhere on the board
/SPAD Sheet/Slow15: R142.1, R144.1; also elsewhere on the board
/SPAD Sheet/Slow16: R145.1, R147.1; also elsewhere on the board
GND: R103.2, R106.2, R109.2, R112.2, R115.2, R118.2, R121.2, R124.2, R127.2, R130.2, R133.2, R136.2, R139.2, R142.2, R145.2; also elsewhere on the board

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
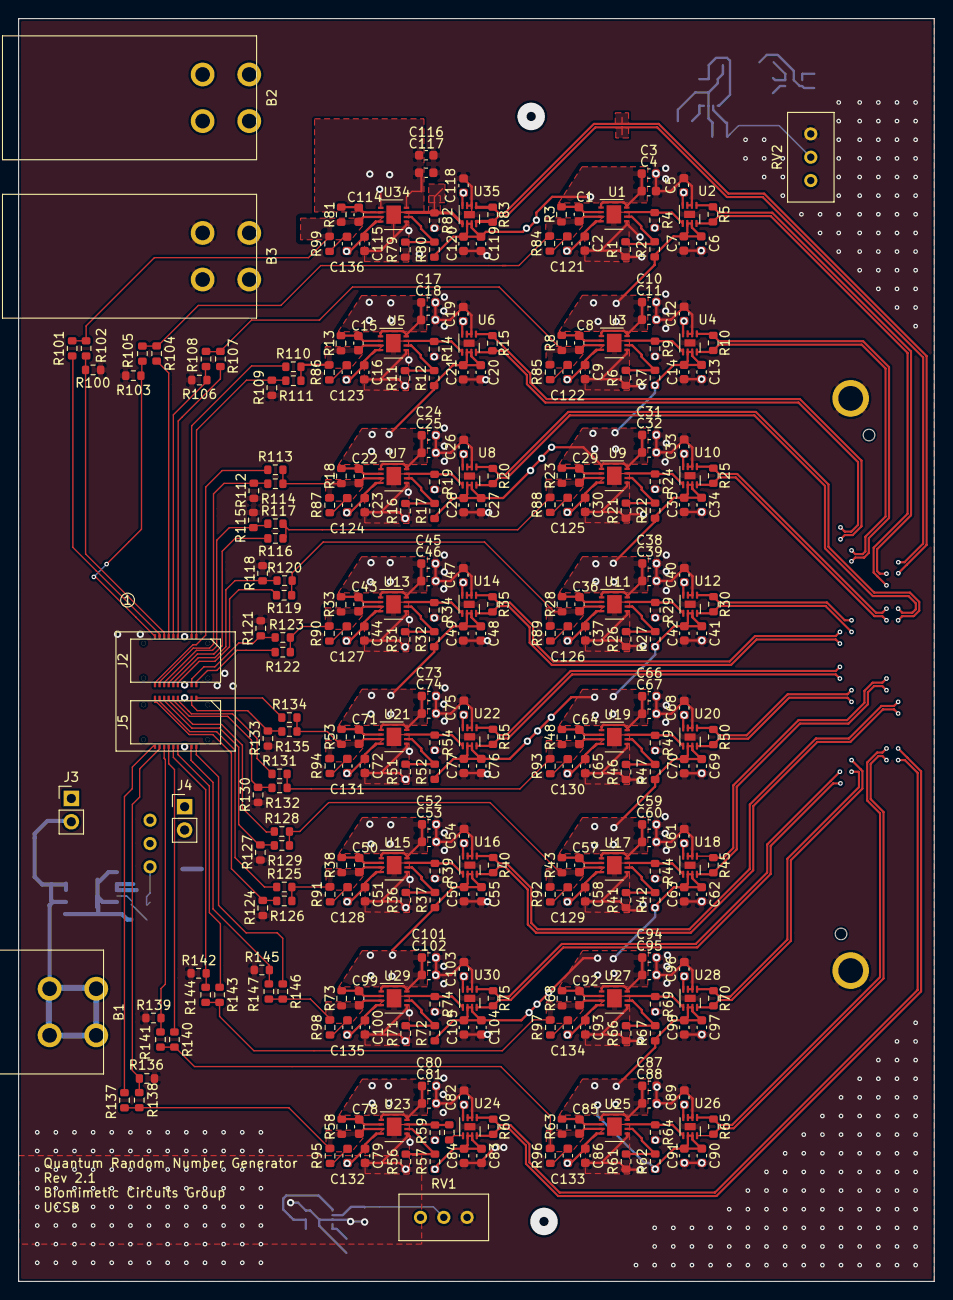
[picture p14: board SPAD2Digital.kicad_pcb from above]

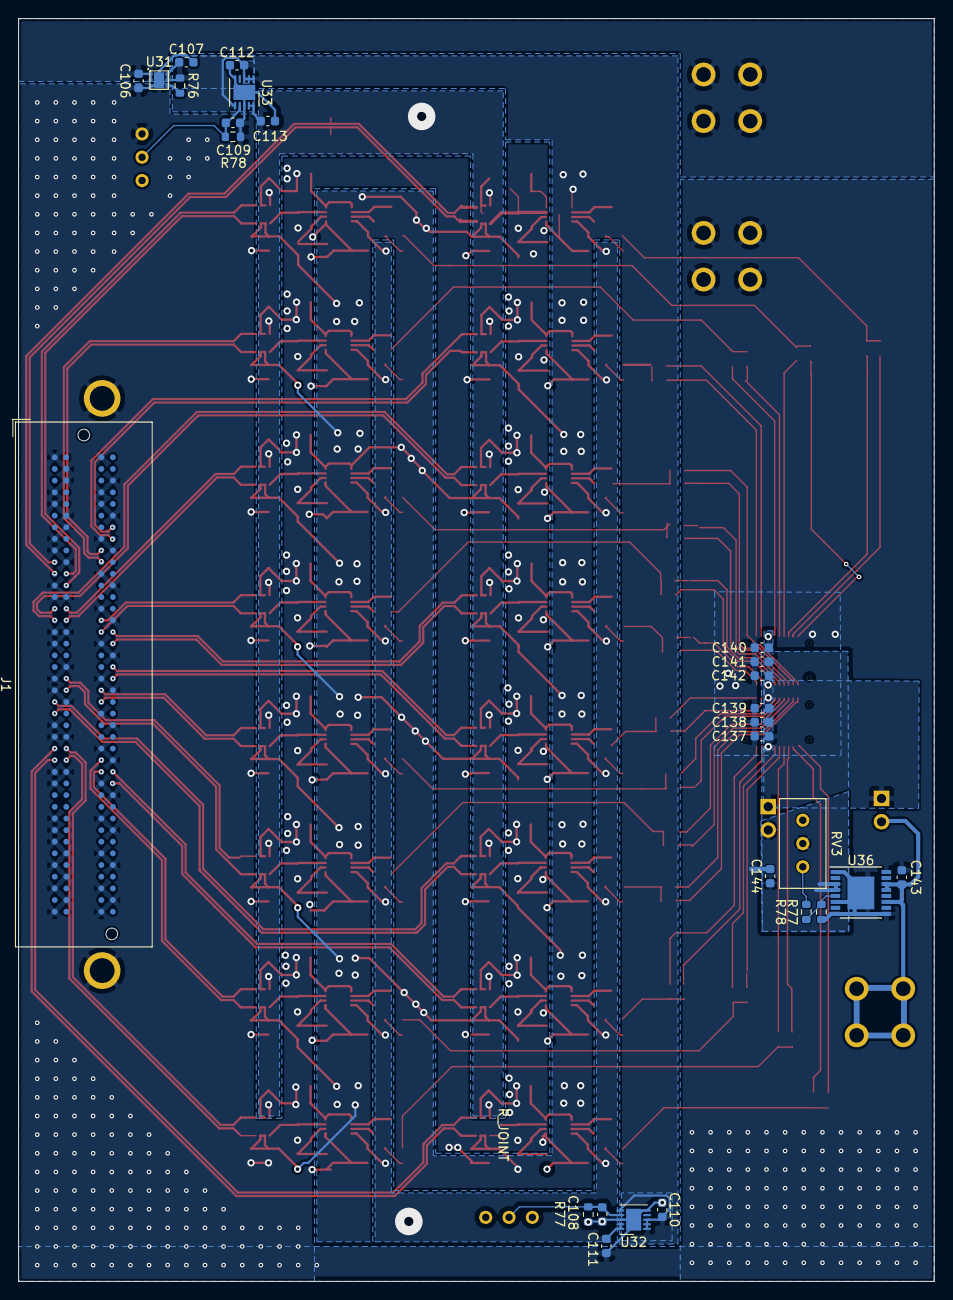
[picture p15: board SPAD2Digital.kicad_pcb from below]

Board: 4 copper layers, 99.8 x 137.7 mm, 341 parts (27 on the bottom side), 157 nets.

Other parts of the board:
R77#2: 2k; R_0603_1608Metric
R78#2: 1k; R_0603_1608Metric
R_JOINT: 0; R_0603_1608Metric

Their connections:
/Channel_D1/TIA_OUT: R_JOINT.1, R_JOINT.2; also elsewhere on the board
GND: R77#2.2, R78#2.2; also elsewhere on the board
unnamed 112: R77#2.1; also elsewhere on the board
unnamed 113: R78#2.1; also elsewhere on the board

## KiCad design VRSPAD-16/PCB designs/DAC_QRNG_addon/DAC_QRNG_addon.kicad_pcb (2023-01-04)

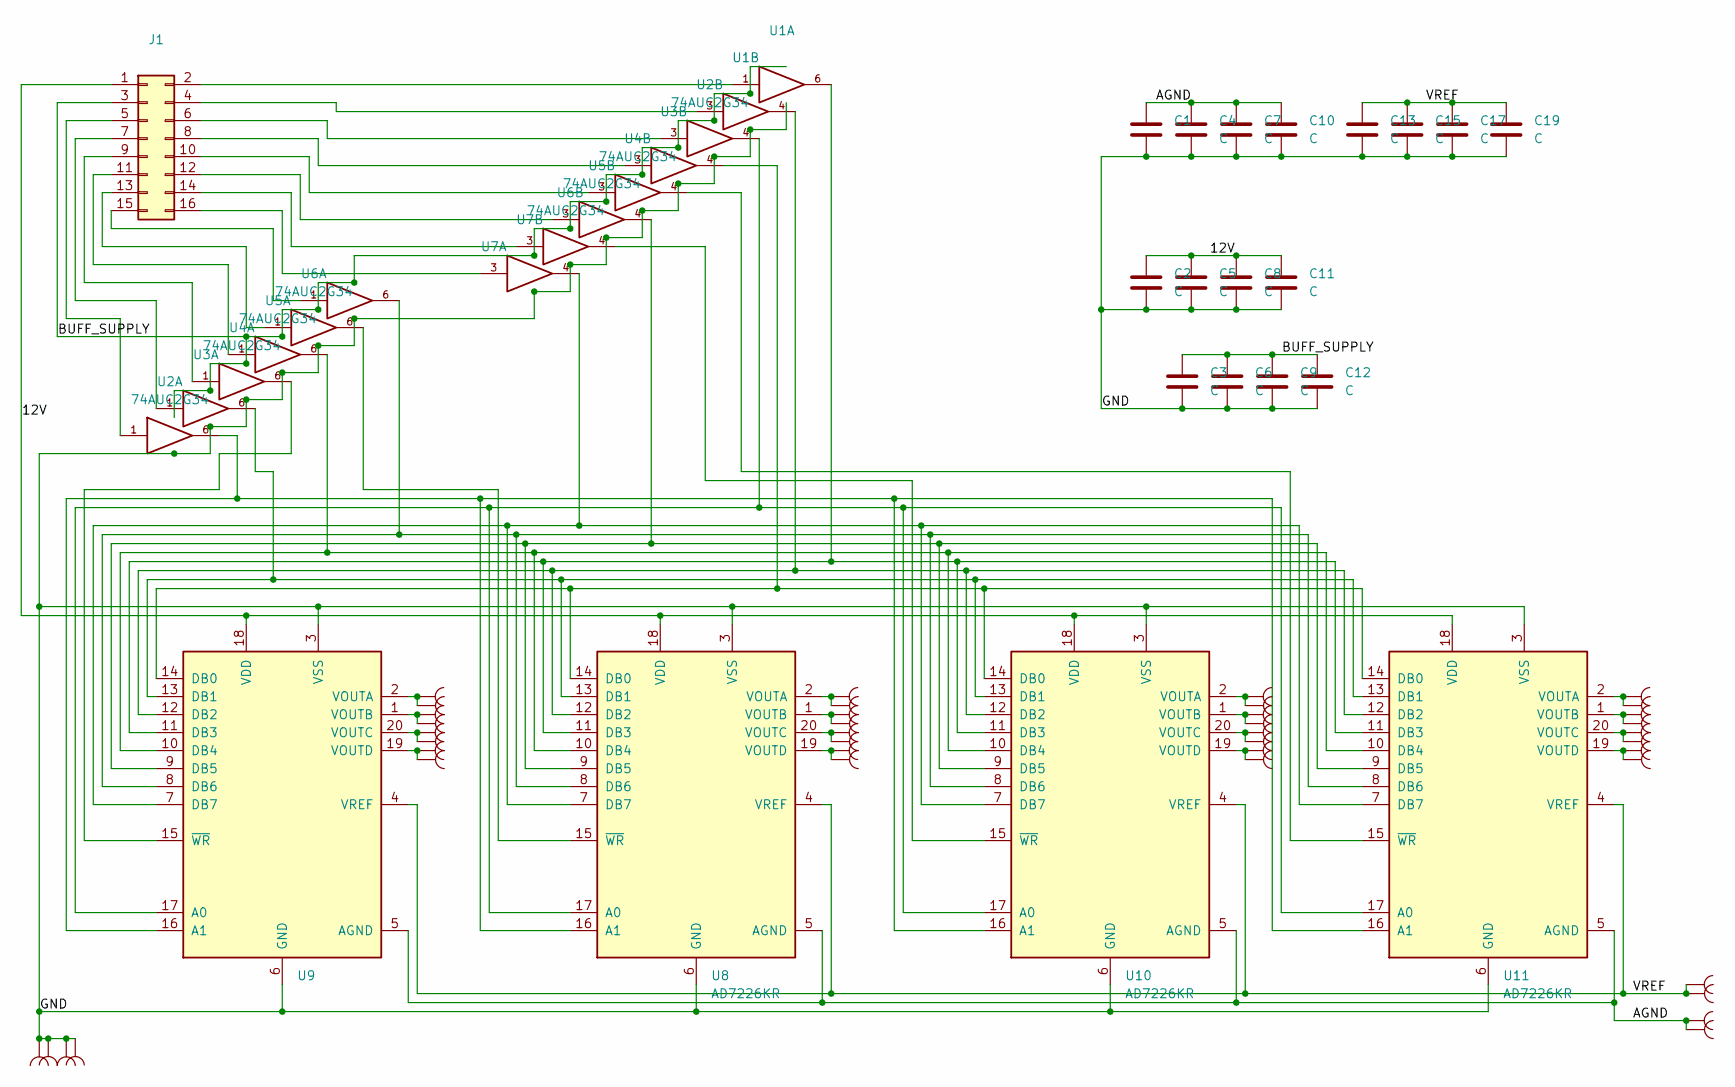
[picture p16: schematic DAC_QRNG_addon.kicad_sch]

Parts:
C1: (no value)
C2, C3, C4, C5, C6, C7, C8, C9, C10, C11, C12, C13, C15, C17, C19: C; C_0603_1608Metric_Pad1.08x0.95mm_HandSolder
J1: (no value)
U1, U3, U7, U9, U28, U29: (no value)
U2, U4, U5, U6: 74AUC2G34; SOT-363_SC-70-6
U8, U10, U11: AD7226KR; SOIC-20W_7.5x12.8mm_P1.27mm
U12, U13, U14, U15, U16, U17, U18, U19, U20, U21, U22, U23, U24, U25, U26, U27, U30, U31: Castle

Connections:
/12V: C2.1, C5.1, C8.1, C11.1, J1.1, U8.18 (VDD), U9.18 (VDD), U10.18 (VDD), U11.18 (VDD)
/AGND: C1.1, C4.1, C7.1, C10.1, U8.5 (AGND), U9.5 (AGND), U10.5 (AGND), U11.5 (AGND), U29.1, U29.2
/VREF: C13.1, C15.1, C17.1, C19.1, U8.4 (VREF), U9.4 (VREF), U10.4 (VREF), U11.4 (VREF), U28.1, U28.2
GND: C1.2, C2.2, C3.2, C4.2, C5.2, C6.2, C7.2, C8.2, C9.2, C10.2, C11.2, C12.2, C13.2, C15.2, C17.2, C19.2, U1.2 (GND), U2.2 (GND), U3.2 (GND), U4.2 (GND), U5.2 (GND), U6.2 (GND), U7.2 (GND), U8.3 (VSS), U8.6 (GND), U9.3 (VSS), U9.6 (GND), U10.3 (VSS), U10.6 (GND), U11.3 (VSS), U11.6 (GND), U30.1, U30.2, U31.1, U31.2
unnamed: J1.5, U2.1
unnamed: J1.6, U2.3
unnamed: J1.9, U4.1
unnamed: J1.10, U4.3
unnamed: J1.13, U6.1
unnamed: J1.14, U6.3
unnamed: J1.2, U1.1
unnamed: J1.4, U1.3
unnamed: J1.7, U3.1
unnamed: J1.8, U3.3
unnamed: J1.11, U5.1
unnamed: J1.12, U5.3
unnamed: U6.6, U8.15 (~WR)
unnamed: J1.15, U7.1
unnamed: J1.16, U7.3
unnamed: U4.6, U9.15 (~WR)
unnamed: U10.1 (VOUTB), U21.1, U21.2
unnamed: U10.2 (VOUTA), U20.1, U20.2
unnamed: U7.4, U8.7 (DB7), U9.7 (DB7), U10.7 (DB7), U11.7 (DB7)
unnamed: U7.6, U8.8 (DB6), U9.8 (DB6), U10.8 (DB6), U11.8 (DB6)
unnamed: U5.4, U8.9 (DB5), U9.9 (DB5), U10.9 (DB5), U11.9 (DB5)
unnamed: U5.6, U8.10 (DB4), U9.10 (DB4), U10.10 (DB4), U11.10 (DB4)
unnamed: U1.6, U8.11 (DB3), U9.11 (DB3), U10.11 (DB3), U11.11 (DB3)
unnamed: U1.4, U8.12 (DB2), U9.12 (DB2), U10.12 (DB2), U11.12 (DB2)
unnamed: U3.6, U8.13 (DB1), U9.13 (DB1), U10.13 (DB1), U11.13 (DB1)
unnamed: U3.4, U8.14 (DB0), U9.14 (DB0), U10.14 (DB0), U11.14 (DB0)
unnamed: U6.4, U10.15 (~WR)
unnamed: U2.6, U8.16 (A1), U9.16 (A1), U10.16 (A1), U11.16 (A1)
unnamed: U2.4, U8.17 (A0), U9.17 (A0), U10.17 (A0), U11.17 (A0)
unnamed: U10.19 (VOUTD), U23.1, U23.2
unnamed: U10.20 (VOUTC), U22.1, U22.2
unnamed: U11.1 (VOUTB), U25.1, U25.2
unnamed: U11.2 (VOUTA), U24.1, U24.2
unnamed: U4.4, U11.15 (~WR)
unnamed: U11.19 (VOUTD), U27.1, U27.2
unnamed: U11.20 (VOUTC), U26.1, U26.2
unnamed: U9.2 (VOUTA), U12.1, U12.2
unnamed: U9.1 (VOUTB), U13.1, U13.2
unnamed: U9.20 (VOUTC), U14.1, U14.2
unnamed: U9.19 (VOUTD), U15.1, U15.2
unnamed: U8.2 (VOUTA), U16.1, U16.2
unnamed: U8.1 (VOUTB), U17.1, U17.2
unnamed: U8.20 (VOUTC), U18.1, U18.2
unnamed: U8.19 (VOUTD), U19.1, U19.2
VCC: C3.1, C6.1, C9.1, C12.1, J1.3, U1.5 (VCC), U2.5 (VCC), U3.5 (VCC), U4.5 (VCC), U5.5 (VCC), U6.5 (VCC), U7.5 (VCC)

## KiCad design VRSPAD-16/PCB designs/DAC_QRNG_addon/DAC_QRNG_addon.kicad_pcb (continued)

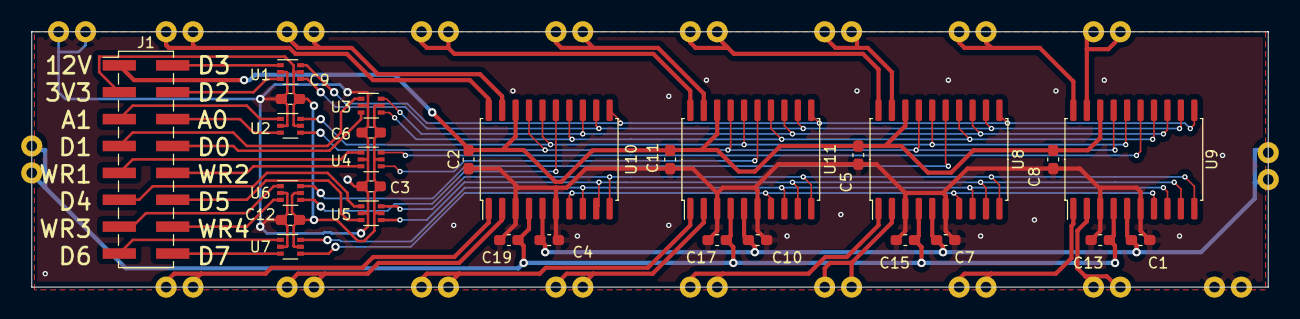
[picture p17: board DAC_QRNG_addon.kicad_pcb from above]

Board: 2 copper layers, 116.8 x 24.1 mm, 48 parts (0 on the bottom side), 49 nets.

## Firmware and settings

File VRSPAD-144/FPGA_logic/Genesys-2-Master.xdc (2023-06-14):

#### This file is a general .xdc for the Genesys 2 Rev. H
#### To use it in a project:
#### - uncomment the lines corresponding to used pins
#### - rename the used ports (in each line, after get_ports) according to the top level signal names in the project

## Clock Signal
#set_property -dict { PACKAGE_PIN AD11  IOSTANDARD LVDS     } [get_ports { sysclk_n }]; #IO_L12N_T1_MRCC_33 Sch=sysclk_n
#set_property -dict { PACKAGE_PIN AD12  IOSTANDARD LVDS     } [get_ports { sysclk_p }]; #IO_L12P_T1_MRCC_33 Sch=sysclk_p

## Buttons
#set_property -dict { PACKAGE_PIN E18   IOSTANDARD LVCMOS12 } [get_ports { btnc }]; #IO_25_17 Sch=btnc
#set_property -dict { PACKAGE_PIN M19   IOSTANDARD LVCMOS12 } [get_ports { btnd }]; #IO_0_15 Sch=btnd
#set_property -dict { PACKAGE_PIN M20   IOSTANDARD LVCMOS12 } [get_ports { btnl }]; #IO_L6P_T0_15 Sch=btnl
#set_property -dict { PACKAGE_PIN C19   IOSTANDARD LVCMOS12 } [get_ports { btnr }]; #IO_L24P_T3_17 Sch=btnr
#set_property -dict { PACKAGE_PIN B19   IOSTANDARD LVCMOS12 } [get_ports { btnu }]; #IO_L24N_T3_17 Sch=btnu
#set_property -dict { PACKAGE_PIN R19   IOSTANDARD LVCMOS33 } [get_ports { cpu_resetn }]; #IO_0_14 Sch=cpu_resetn

## LEDs
#set_property -dict { PACKAGE_PIN T28   IOSTANDARD LVCMOS33 } [get_ports { led[0] }]; #IO_L11N_T1_SRCC_14 Sch=led[0]
#set_property -dict { PACKAGE_PIN V19   IOSTANDARD LVCMOS33 } [get_ports { led[1] }]; #IO_L19P_T3_A10_D26_14 Sch=led[1]
#set_property -dict { PACKAGE_PIN U30   IOSTANDARD LVCMOS33 } [get_ports { led[2] }]; #IO_L15N_T2_DQS_DOUT_CSO_B_14 Sch=led[2]
#set_property -dict { PACKAGE_PIN U29   IOSTANDARD LVCMOS33 } [get_ports { led[3] }]; #IO_L15P_T2_DQS_RDWR_B_14 Sch=led[3]
#set_property -dict { PACKAGE_PIN V20   IOSTANDARD LVCMOS33 } [get_ports { led[4] }]; #IO_L19N_T3_A09_D25_VREF_14 Sch=led[4]
#set_property -dict { PACKAGE_PIN V26   IOSTANDARD LVCMOS33 } [get_ports { led[5] }]; #IO_L16P_T2_CSI_B_14 Sch=led[5]
#set_property -dict { PACKAGE_PIN W24   IOSTANDARD LVCMOS33 } [get_ports { led[6] }]; #IO_L20N_T3_A07_D23_14 Sch=led[6]
#set_property -dict { PACKAGE_PIN W23   IOSTANDARD LVCMOS33 } [get_ports { led[7] }]; #IO_L20P_T3_A08_D24_14 Sch=led[7]

## Switches
#set_property -dict { PACKAGE_PIN G19   IOSTANDARD LVCMOS12 } [get_ports { sw[0] }]; #IO_0_17 Sch=sw[0]
#set_property -dict { PACKAGE_PIN G25   IOSTANDARD LVCMOS12 } [get_ports { sw[1] }]; #IO_25_16 Sch=sw[1]
#set_property -dict { PACKAGE_PIN H24   IOSTANDARD LVCMOS12 } [get_ports { sw[2] }]; #IO_L19P_T3_16 Sch=sw[2]
#set_property -dict { PACKAGE_PIN K19   IOSTANDARD LVCMOS12 } [get_ports { sw[3] }]; #IO_L6P_T0_17 Sch=sw[3]
#set_property -dict { PACKAGE_PIN N19   IOSTANDARD LVCMOS12 } [get_ports { sw[4] }]; #IO_L19P_T3_A22_15 Sch=sw[4]
#set_property -dict { PACKAGE_PIN P19   IOSTANDARD LVCMOS12 } [get_ports { sw[5] }]; #IO_25_15 Sch=sw[5]
#set_property -dict { PACKAGE_PIN P26   IOSTANDARD LVCMOS33 } [get_ports { sw[6] }]; #IO_L10P_T1_D14_14 Sch=sw[6]
#set_property -dict { PACKAGE_PIN P27   IOSTANDARD LVCMOS33 } [get_ports { sw[7] }]; #IO_L8P_T1_D11_14 Sch=sw[7]

## USB HIDs For Both Mouse and Keyboard
#set_property -dict { PACKAGE_PIN AD23  IOSTANDARD LVCMOS33  PULLUP true } [get_ports { ps2_clk_0 }]; #IO_L12P_T1_MRCC_12 Sch=ps2_clk[0]
#set_property -dict { PACKAGE_PIN AE20  IOSTANDARD LVCMOS33  PULLUP true } [get_ports { ps2_data_0 }]; #IO_25_12 Sch=ps2_data[0]

## UART
#set_property -dict { PACKAGE_PIN Y23   IOSTANDARD LVCMOS33 } [get_ports { uart_rx_out }]; #IO_L1P_T0_12 Sch=uart_rx_out
#set_property -dict { PACKAGE_PIN Y20   IOSTANDARD LVCMOS33 } [get_ports { uart_tx_in }]; #IO_0_12 Sch=uart_tx_in

## SD Card
#set_property -dict { PACKAGE_PIN P28   IOSTANDARD LVCMOS33 } [get_ports { sd_cd }]; #IO_L8N_T1_D12_14 Sch=sd_cd
#set_property -dict { PACKAGE_PIN R29   IOSTANDARD LVCMOS33 } [get_ports { sd_cmd }]; #IO_L7N_T1_D10_14 Sch=sd_cmd
#set_property -dict { PACKAGE_PIN R26   IOSTANDARD LVCMOS33 } [get_ports { sd_d[0] }]; #IO_L10N_T1_D15_14 Sch=sd_dat[0]
#set_property -dict { PACKAGE_PIN R30   IOSTANDARD LVCMOS33 } [get_ports { sd_d[1] }]; #IO_L9P_T1_DQS_14 Sch=sd_dat[1]
#set_property -dict { PACKAGE_PIN P29   IOSTANDARD LVCMOS33 } [get_ports { sd_d[2] }]; #IO_L7P_T1_D09_14 Sch=sd_dat[2]
#set_property -dict { PACKAGE_PIN T30   IOSTANDARD LVCMOS33 } [get_ports { sd_d[3] }]; #IO_L9N_T1_DQS_D13_14 Sch=sd_dat[3]
#set_property -dict { PACKAGE_PIN AE24  IOSTANDARD LVCMOS33 } [get_ports { sd_reset }]; #IO_L12N_T1_MRCC_12 Sch=sd_reset
#set_property -dict { PACKAGE_PIN R28   IOSTANDARD LVCMOS33 } [get_ports { sd_sclk }]; #IO_L11P_T1_SRCC_14 Sch=sd_sclk
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

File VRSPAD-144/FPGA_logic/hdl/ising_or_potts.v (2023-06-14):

//main logic module for VRSPAD-144 demo system.
//includes:
//4 banks of pipelined adders feeding directly into the DAC writeback channels (setting thresholds on the PCB);
//counters to measure VRSPAD transfer characteristics;
//low-energy checking module to keep track of the best-solution-so-far;
//several slave SPI interfaces for configuring and sending data to a host computer via an FTDI chip:
//  one 4-byte interface for setting general configuration values and reading some performance results,
//  one 18-byte (144 bit) interface for reading the boltzmann machine state,
//  one 146-byte interface for writing boltzmann machine weights into block memory for use by the pipelined adders 

//Author: William Whitehead
//Date: April 2023

module ising_or_potts(
        //200 MHz input clock - recieved differentially
        input sysclk_n,
        input sysclk_p,

        //connected to reset pin on genesys 2 fpga board
        input cpu_resetn,

        //inputs from VRSPAD circuits
        input wire [144:1] pulse_in,
        
        //threshold DAC outputs
        output reg [7:0] BUS1,
        output reg [7:0] BUS2,
        output reg [7:0] BUS3,
        output reg [7:0] BUS4,
        output reg [1:0] A,
        output reg [9:1] WR,
        output reg HBEN,

        //LED, for basic functionality checking
        output wire [7:0] led,
        
        //SPI interface to FTDI chip for interfacing configration and results to a PC:
        input wire sck,
        input wire mosi,
        output reg miso,
        input wire cs2,
        input wire cs3,
        input wire cs4,
        input wire cs5
    );
    genvar i, k;
    integer j;

    wire clk200;
    reg clk100, clk;
    IBUFDS buf1(.I(sysclk_p), .IB(sysclk_n), .O(clk200));  //differential to single-ended
    
    always @(posedge clk200) clk100 <= ~clk100;
    always @(posedge clk100) clk <= ~clk;

    ///////////////////////////////////////////////////////////////////////////////////////////////////////////////////////
    //pre-process SPAD signals ==============================================================================================================
    reg [143:0] edge_reg_1, spad_pulse_sync, spad_pulse_sync_gated;
        
    // edge-detecting registers for processing SPAD inputs:   
    for (i=0; i<144; i=i+1) begin
        always @(posedge clk) begin
            edge_reg_1[i] <= pulse_in[i+1];
            spad_pulse_sync[i] <= (pulse_in[i+1] & ~edge_reg_1[i]); //async to sync
            spad_pulse_sync_gated[i] = 0;//(DAC_pointer > update_delay) & (pulse_in[i+1] & ~edge_reg_1[i]);
        end
    end
    
    //////////////////////////////////////////////////////////////////////////////////////////////////////////////////////////
    //phase pointer: controls when threshold DACs are written to, and when to halt reception of the VRSPAD pulses

    reg [7:0] phase_pointer; //a counter that controls when everything happens
    wire [7:0] cycle_period; //a config input; determines when to reset the phase pointer
    wire [7:0] pulse_disable_period; //a config input; determines when to ignore VRSPAD pulses
    // (since DAC update introduces noise etc, want to ignore pulses during that time)

    always @(posedge clk) begin
        //incrimenting the phase pointer
        if (phase_pointer == cycle_period) phase_pointer <= 0;
        else 
        phase_pointer <= phase_pointer + 1;

    end


    ////////////////////////////////////////////////////////////////////////////////////////////////////////////////////////////////////
    //SPAD frequency counters ==========================================================================================================
    wire count_enable; // a cfg input, manually toggled in code
    wire count_reset; //a cfg input, manually toggled in code
    wire count_active;
    assign count_active = count_enable & (phase_pointer > pulse_disable_period);

    reg [31:0] raw_counters[143:0];
    reg [31:0] clked_counters[143:0];
    reg [31:0] count_timer;

    // reg [31:0] flip_counters[143:0];
    // reg [143:0] last_bm_state;

    always @(posedge clk) begin
        if (count_reset) count_timer <= 0;
        else if (count_active) count_timer <= count_timer + 1;
    end
    
    for (i=0; i<144; i=i+1) begin
        always @(posedge clk) begin
            if (count_reset) clked_counters[i] <= 0;
            else if (count_active && spad_pulse_sync[i]) clked_counters[i] <= clked_counters[i] + 1;
        end
        always @(posedge pulse_in[i+1]) begin
            if (count_reset) raw_counters[i] <= 0;
            else if (count_active) raw_counters[i] <= raw_counters[i] + 1; //incriment counter - we get one 8-bit random number on each positive edge
        end    
        // always @(posedge clk) begin
            // if (man_rst) flip_counters[i] <= 0;
            // else if (count_enable && (bm_state[i]^last_bm_state[i])) flip_counters[i] <= flip_counters[i] + 1; //incriment counter - we get one 8-bit random number on each positive edge
        // end    
    end


    //////////////////////////////////////////////////////////////////////////////////////////////////////////////////
    //main BM instantiation:
    //-latches
    //-energy sums
    //-DAC writing
    //all snchronized/controlled by a master phase pointer which indicates when each sum is calculated and sent to the DACs



    //latch parts
    wire [143:0] bm_state;
    wire BM_enable;
    assign BM_enable = (phase_pointer > pulse_disable_period);

    //mostly just settings from the config interface, padded with an extra 1'b1 bit:
    wire [144:0] cuts;

    latch_chain latches(clk, BM_enable, spad_pulse_sync, cuts, bm_state);

    //summation parts - there are 4 pipelined summation units, drawing off of banks of block RAM.
    //the BRAM is written to using a SPI interface that does 147-byte long transfers (one address, one self-index, one bias, and 144 weights)
    wire signed [11:0] group1energy, group2energy, group3energy, group4energy; //outputs for solution checking
    wire [7:0] group1dac, group2dac, group3dac, group4dac; //outputs for threshold writing
    wire [1:0] sum_shift_amnt;
    piplined_energy_calc group1(cs3, mosi, sck, clk, bm_state, phase_pointer, sum_shift_amnt, group1energy, group1dac);
    piplined_energy_calc group2(cs3, mosi, sck, clk, bm_state, phase_pointer+36, sum_shift_amnt, group2energy, group2dac);
    piplined_energy_calc group3(cs3, mosi, sck, clk, bm_state, phase_pointer+72, sum_shift_amnt, group3energy, group3dac);
    piplined_energy_calc group4(cs3, mosi, sck, clk, bm_state, phase_pointer+108, sum_shift_amnt, group4energy, group4dac);

    //not used to program the delay, but just to indicate the pipeline depth for other RTL that needs to be synchronized
    parameter sum_delay = 8;
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

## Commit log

2023-01-04 Add files via upload
    Added PCB designs, operating code and Jupyter notebook from Zedboard local space, and a Vivado 2020.1 project for Zedboard configuration.
    [Bias_Circuitry.sch, Channel.sch, DAC_QRNG_addon - layout 1.kicad_pcb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]
2023-06-14 added design files for 144-circuit experimental demonstration
    [Bias_Circuitry.sch, Channel.sch, DAC_QRNG_addon - layout 1.kicad_pcb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]
2023-06-14 updated readme to reflect 144-circuit system
